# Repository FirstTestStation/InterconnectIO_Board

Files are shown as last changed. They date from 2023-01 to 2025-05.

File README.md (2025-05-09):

# FIRST STATION TEST Interconnect IO Board 600-1000-011

## Project Overview
This project involves the assembly of a custom **Interconnect IO Circuit Board (PCB)** designed to be part of the **First TestStation** project ([FTS](https://FirstTestSTation.github.io/FTS_Website/)). The primary goal of the Interconnect IO board is to provide an interface between instruments and the Unit Under Test (U.U.T).

Many resources, such as **bank relays**, **power relays**, **Digital IO** and **communication interfaces**, have been integrated into the Interconnect IO board. These resources reduce the need for external instruments and maximize the versatility of the interface, allowing for efficient testing and broader functionality.

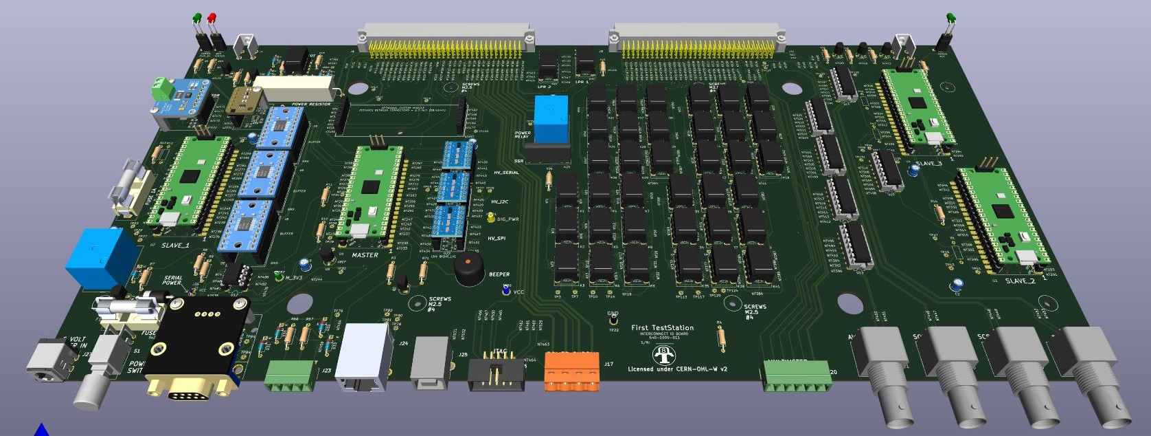
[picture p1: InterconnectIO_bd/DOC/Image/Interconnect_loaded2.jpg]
Board
 

### Design Tools
- [KiCad 7](https://www.kicad.org/download/) - Free software application used to design the PCB.
- [LibreOffice](https://www.libreoffice.org/download/download-libreoffice/) - Free Software application used to create assembly instructions and the Bill of Materials (BOM).
- [PicPick](https://picpick.app/en/) - Free application to capture and document image.

---
### Features
- **Easy Hand Assembly**: Designed with only through-hole components, making it easy to assemble by hand.
- **Socketed Active Components**: To facilitate easy replacement without unsoldering, most active components are mounted on sockets.
- **Cost-Effective Controller**: The low-cost and powerful **Raspberry Pi Pico Microcontroller** is used to interface with the user and control internal electronics.

## Assembly Instructions
   Follow the document [Assembly_Instructions](InterconnectIO_bd/pdf/InterconnectIO_Assembly_Instruction_680-1000.pdf) to complete the assembly of the board.

## Design Files
- [Gerber Files](InterconnectIO_bd/gerber_to_order/) – Gerber files for PCB fabrication, send zip file to manufacturer (JLCPCB is the one used by the project).
- [Assembly Schematic](InterconnectIO_bd/pdf/InterconnectIO_Assembly_diagram_670-1000.pdf) – Parts and value to help hand assemblies of components.
- [Electrical Schematic](InterconnectIO_bd/pdf/interconnectIO_schematic_640-1000.pdf) – Review the full electrical schematic diagram for reference.
- [Bill of Materials (BOM)](InterconnectIO_bd/pdf/BOM_InterconnectIO_Board_610-1000.pdf) – List of components required for assembly.

---

## License

This project is licensed under the terms of the [CERN Open Hardware License Version 2 - Weakly Reciprocal (CERN-OHL-W 2.0)](https://ohwr.org/cern_ohl_w_v2.txt).

See the [LICENSE](./LICENSE) file in this repository for more details.

---

## History
- **Version 1.0**: The initial version of the PCB (600-1010-010) has been assembled and tested. Wiring errors on the UART were identified and corrected manually using wires.
- **Version 1.1**: This version addresses all errors identified in Version 1.0. As of now, Version 1.1 has not yet been assembled or tested.
---

## Contact
For any issues or further questions, feel free to contact me at [daniellockhead@gmail.com] or open an issue on GitHub.

---

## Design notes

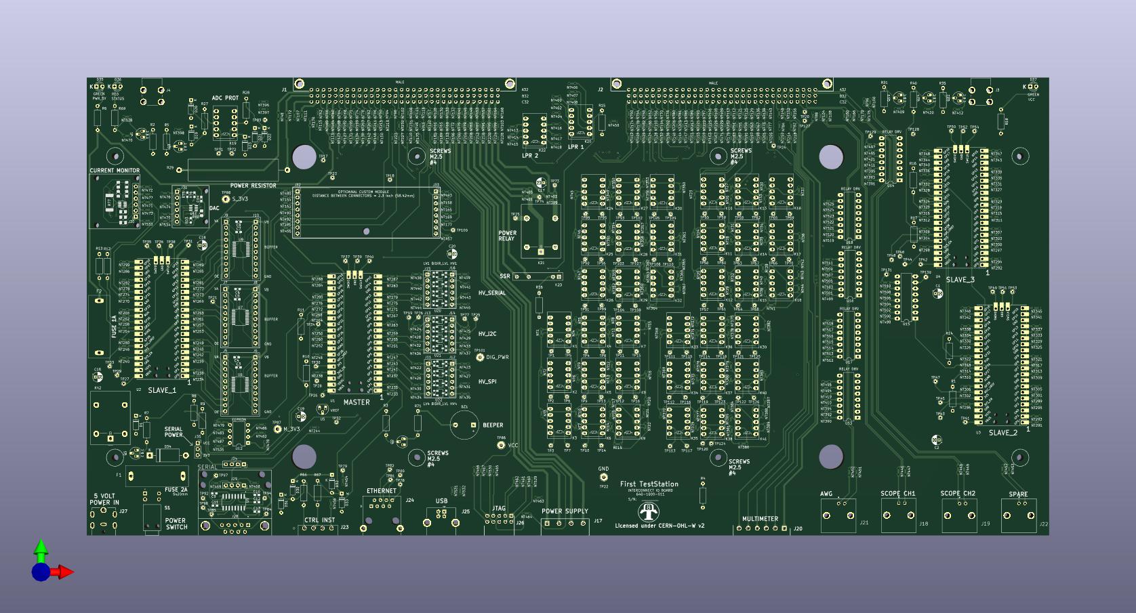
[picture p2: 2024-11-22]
InterconnectIO_bd/DOC/Image/Interconnect_PCB.jpg

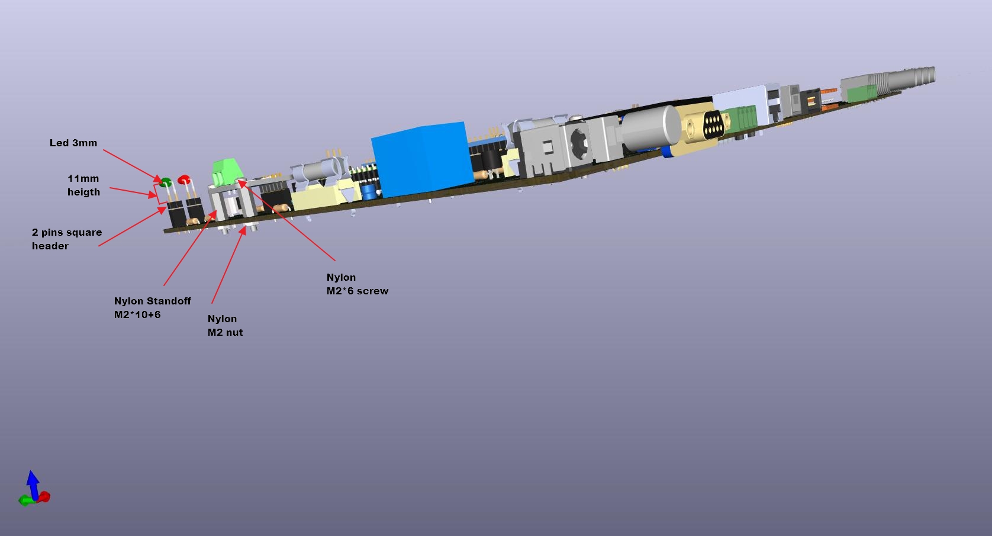
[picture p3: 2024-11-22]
InterconnectIO_bd/DOC/Image/Interconnect_mount3.jpg

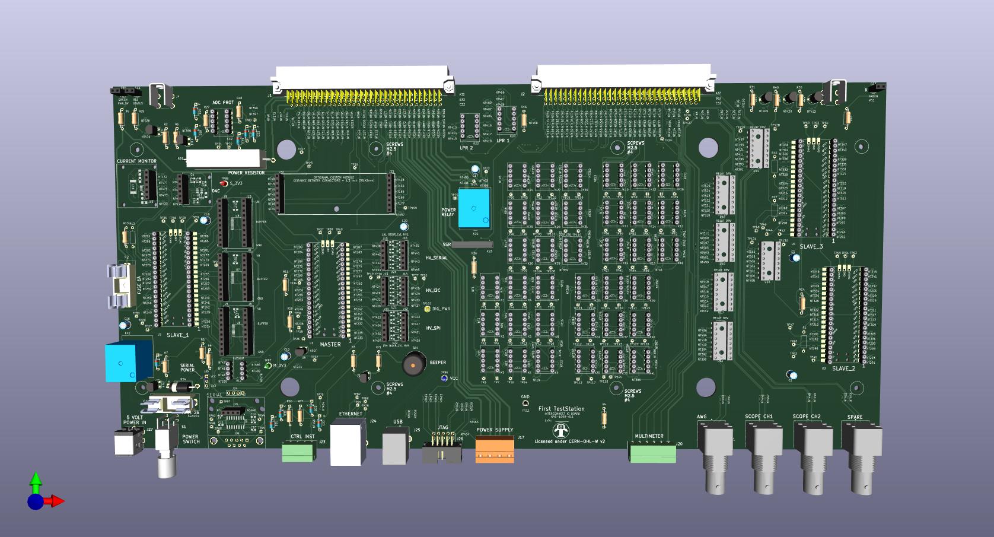
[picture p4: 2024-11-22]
InterconnectIO_bd/DOC/Image/Interconnect_mount.jpg

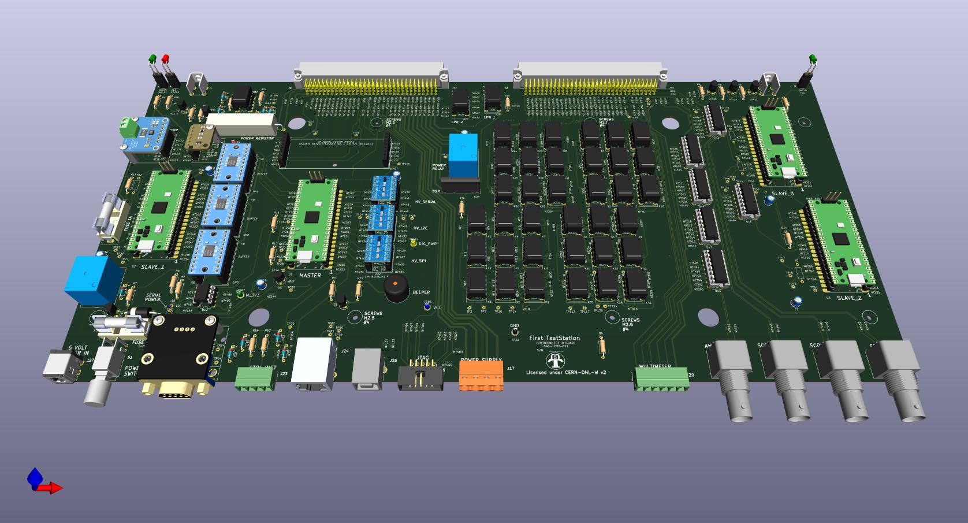
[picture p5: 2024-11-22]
InterconnectIO_bd/DOC/Image/Interconnect_mount2.jpg

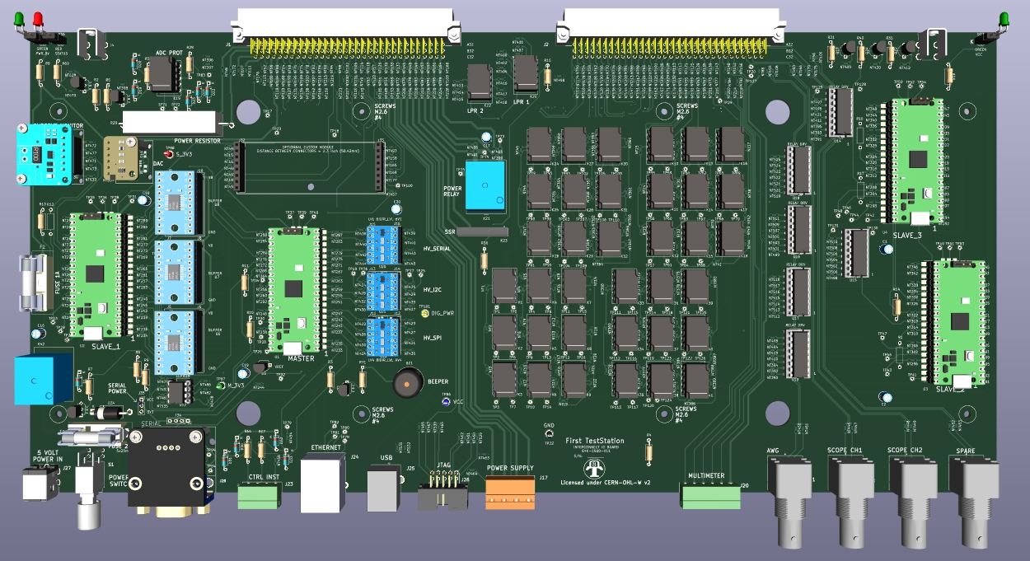
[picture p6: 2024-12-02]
InterconnectIO_bd/DOC/Image/Interconnect_loaded.jpg

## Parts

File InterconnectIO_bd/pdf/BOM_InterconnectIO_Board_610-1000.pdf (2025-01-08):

# BOM InterconnectIO Board

610-1000-011

Component for this board has been selected to be not expensive and available over the world. The quanty specified on the BOM are the required quanty and not the quanty received because most of the components sales by AlieExpress are coming in a lot of 5 or m

ITEM Ref | Qty Value | Component number | Component Link | Footprint
1 | BZ1, | 1 | TMB12A05 | 5V acve Buzzer | hps://www.aliexpress.com/item/4000118703011.html?spm=a2g0o.order_list.order_list_main.124.18751802TGrCM3 | Buzzer_Beeper:Buzzer_12x9.5RM7.6
2 | C1, C2, C16, C17, C18, C19, C20, | 7 | 10uF, 50V | 4 mmx7mm | hps://www.aliexpress.com/item/1005001831366715.html?spm=a2g0o.order_list.order_list_main.128.18751802TGrCM3 | Capacitor_THT:CP_Radial_D4.0mm_P1.50mm
3 | D1, D19, D20, D21, D22, D23, D30, D31, D32, D310 | | 1N4148 | DO-35 | hps://www.aliexpress.com/item/1005002761024460.html?spm=a2g0o.order_list.order_list_main.134.18751802TGrCM3 | Diode_THT:D_DO-35_SOD27_P7.62mm_Horizontal
4 | D34, | 1 | 1N5339B | Zener 5.6V 5W | hps://www.aliexpress.com/item/1005007252102432.html?spm=a2g0o.cart.0.0.382738davUv7k5&mp=1 | Diode_THT:D_DO-201_P15.24mm_Horizontal
5 | D35, D37 | 2 | Green Led | 5 color mixing | hps://www.aliexpress.com/item/32890682652.html?spm=a2g0o.cart.0.0.484b38da3R3jzV&mp=1 | LED_THT:LED_D3.0mm
6 | D36, | 1 | Red Led | 5 color mixing | hps://www.aliexpress.com/item/32890682652.html?spm=a2g0o.cart.0.0.484b38da3R3jzV&mp=1 | LED_THT:LED_D3.0mm_Clear
7 | F1 | 1 | 2A Fuse | 5x20MM 2A | hps://www.aliexpress.com/item/1005004651911205.html?spm=a2g0o.cart.0.0.1c8438daX57J70&mp=1
8 | F2 | 1 | 1A Fuse | 5x20MM 1A | hps://www.aliexpress.com/item/1005004651911205.html?spm=a2g0o.cart.0.0.1c8438daX57J70&mp=1
9 | F1_socket F2_socket, | 2 | MC000827 | MC000827 | hps://www.aliexpress.com/item/1005003663678449.html?spm=a2g0o.order_list.order_list_main.109.5ad91802qJ50cl | SnapEDA Library:MC000827
10 | J1, J2, | 2 | 9001-11961C00A | 396-RA-M | hps://www.aliexpress.com/item/32808173331.html?spm=a2g0o.order_detail.order_detail_item.3.8a9af19cRF49dn | 9001-11961:900111961C00A
11 | J3, J4, | 2 | 7760 | M3 Term Screw | hps://www.digikey.ca/en/products/detail/keystone-electronics/7760/2745938 | SnapEDA Library:7760
12 | J5, J6, J7, J8, J9, J10, | 6 | 10x2.54mm | Cut to length | hps://www.aliexpress.com/item/1000007373786.html?spm=a2g0o.order_list.order_list_main.82.21ef18021ieJzP | Connector_PinSocket_2.54mm:PinSocket_1x10_P2.54mm_Vercal
13 | J11, J12, J13, J14, J15, J16, J30, J31, | 8 | 6x2.54mm | Cut to length | hps://www.aliexpress.com/item/1000007373786.html?spm=a2g0o.order_list.order_list_main.82.21ef18021ieJzP | Connector_PinSocket_2.54mm:PinSocket_1x06_P2.54mm_Vercal
14 | J17, | 1 | 4 Pins 5.08mm | 4P | hps://www.aliexpress.com/item/1005001666625465.html?spm=a2g0o.order_list.order_list_main.134.21ef18021ieJzP | 4pin_5:1146770000
15 | J18, J19,J21,J22 | 4 | BNC | Conn_Coaxial gold plated | hps://www.aliexpress.com/item/1005006866967010.html?spm=a2g0o.cart.0.0.5dcc38daPY7vC2&mp=1 | BNC:TE_1-1337542-0
16 | J20, | 1 | 6 pins 3.81mm | 6P 3.81mm Plug and Socket-A | hps://www.aliexpress.com/item/32880910367.html?spm=a2g0o.order_detail.order_detail_item.3.2a65f19ceWcMGt | 6pin_3:SHDRRA6W80P0X381_1X6_2405X920X700P
17 | J23, | 1 | 4 pins 3.81mm | 4P 3.81mm Plug and Socket-A | hps://www.aliexpress.com/item/32880910367.html?spm=a2g0o.order_detail.order_detail_item.3.7110f19cKK7wMr | 4pins_3:691322310004
18 | J24, | 1 | RJ45 | 8P8C Right Angle No led | hps://www.aliexpress.com/item/32694863099.html?spm=a2g0o.cart.0.0.7fd538dawwnp2x&mp=1 | Connector_RJ:RJ45_Ninigi_GE
19 | J25, | 1 | USB-B1HSB6 | USB_B Right Angle | hps://www.aliexpress.com/item/32834923469.html?spm=a2g0o.order_list.order_list_main.34.21ef18021ieJzP | Connector_USB:USB_B_OST_USB-B1HSxx_Horizontal
20 | J26, | 1 | 2x5 2.54mm RA | 10P | hps://www.aliexpress.com/item/1714360661.html?spm=a2g0o.order_list.order_list_main.29.21ef18021ieJzP | Connector_jtag:SHDRRA10W64P254_2X5_1270X910X880P
21 | J27, | 1 | DC007B | Power Jack 5.5mm | hps://www.aliexpress.com/item/1005003742132830.html?spm=a2g0o.order_detail.order_detail_item.3.5979f19cN90o6a | SnapEDA Library:CUI_PJ-082BH
22 | J29, J34, | 2 | Conn_01x04_Female | Cut to length | hps://www.aliexpress.com/item/1000007373786.html?spm=a2g0o.order_list.order_list_main.82.21ef18021ieJzP | Connector_PinSocket_2.54mm:PinSocket_1x04_P2.54mm_Vercal
23 | J32, J33, | 2 | 8 x 2.54mm Female | Cut to length | hps://www.aliexpress.com/item/1000007373786.html?spm=a2g0o.order_list.order_list_main.82.21ef18021ieJzP | Connector_PinSocket_2.54mm:PinSocket_1x08_P2.54mm_Vercal
24 | J35, | 1 | Wire Bridge | 0 ohm resistor | hps://www.aliexpress.com/item/4000174550644.html?spm=a2g0o.cart.0.0.69c038dacU7SYy&mp=1 | Connector_PinSocket_2.54mm:PinSocket_1x03_P2.54mm_Vercal
25 | K12, K13, K14, K15, K16, K17, K18, K19, K20, K22, K24, K25, K26, K27, K28, K29, K30, K31, K32, K33, K34, K35, K36, K37, K38, K39, K40, K41, | 39 | TQ2-5 | TQ2-5 | hps://www.aliexpress.com/item/1005004349797638.html?spm=a2g0o.order_detail.order_detail_item.3.29bdf19cH6EBpl | Relay_THT:Relay_DPDT_FRT5
26 | Relay Socket | 10 | 1x40P Female Gold | Cut in 5 pins secon | hps://www.aliexpress.com/item/1005005053790061.html?spm=a2g0o.order_list.order_list_main.16.2c1a1802vA8wf5 | oponnal
27 | K21, K42 | 2 | SRD-5VDC-SL-C | SRD-05VDC-SL | hps://www.aliexpress.com/item/1005002916764977.html?spm=a2g0o.cart.0.0.678938dalwTZ3N&mp=1 | Relay_THT:Relay_SPDT_Omron-G5LE-1
28 | K23, | 1 | CPC1706Y | 0-60V 4A | hps://www.digikey.ca/en/products/detail/ixys-integrated-circuits-division/CPC1706Y/3077519?s=N4IgTCBcDaIMIAU4EYDsAGAbATRAXQF8g | SnapEDA Library:RELAY_CPC1706Y
29 | Q1, Q2, Q3, Q5, Q19, Q22, Q24, | 7 | 2N2222 | TO-92 | hps://www.aliexpress.com/item/1005005303849667.html?spm=a2g0o.cart.0.0.5c5438daSYNCOD&mp=1 | Package_TO_SOT_THT:TO-92_Inline
30 | R1, R10, R11, R12, R13, R14, R15,R16, R17, | 9 | 4.7K | 1% 1/4W Resistor Kit | hps://www.aliexpress.com/item/1005001818485416.html?spm=a2g0o.cart.0.0.616b38daL0tFWh&mp=1 | Resistor_THT:R_Axial_DIN0207_L6.3mm_D2.5mm_P10.16mm_Horizontal
31 | R2, R3, R5, R7, R8, R9, R31, R35, R40, | 9 | 10K | 1% 1/4W Resistor Kit | hps://www.aliexpress.com/item/1005001818485416.html?spm=a2g0o.cart.0.0.616b38daL0tFWh&mp=1 | Resistor_THT:R_Axial_DIN0207_L6.3mm_D2.5mm_P10.16mm_Horizontal
32 | R4, R71, | 2 | 0 | 1% 1/4W Low value Resistor Kit | hps://www.aliexpress.com/item/4000174550644.html?spm=a2g0o.cart.0.0.69c038dacU7SYy&mp=1 | Resistor_THT:R_Axial_DIN0207_L6.3mm_D2.5mm_P10.16mm_Horizontal
33 | R6, R27, R28, R66, R67, R18 | 5 | 220 | 1% 1/4W Resistor Kit | hps://www.aliexpress.com/item/1005001818485416.html?spm=a2g0o.cart.0.0.405a38daqyYISw&mp=1 | Resistor_THT:R_Axial_DIN0207_L6.3mm_D2.5mm_P10.16mm_Horizontal
34 | R29, | 1 | 10 | 10W 10R | hps://www.aliexpress.com/item/1005002584950177.html?spm=a2g0o.order_list.order_list_main.76.68501802kRK9e9 | Resistor_THT:R_Axial_Power_L38.0mm_W9.0mm_P45.72mm
35 | R36, | 1 | 470 | 1% 1/4W Resistor Kit | hps://www.aliexpress.com/item/1005001818485416.html?spm=a2g0o.cart.0.0.616b38daL0tFWh&mp=1 | Resistor_THT:R_Axial_DIN0207_L6.3mm_D2.5mm_P10.16mm_Horizontal
36 | R69, | 1 | 150 | 1% 1/4W Resistor Kit | hps://www.aliexpress.com/item/1005001818485416.html?spm=a2g0o.cart.0.0.616b38daL0tFWh&mp=1 | Resistor_THT:R_Axial_DIN0207_L6.3mm_D2.5mm_P10.16mm_Horizontal
37 | S1, | 1 | PB400EEQR1BLK | PB400EEQR1BLK | hps://www.digikey.ca/en/products/detail/e-switch/PB400EEQR1BLK/8042726 | SnapEDA Library:SW_PB400EEQR1BLK
38 | U1, U2, U3, U4, | 4 | Pico | Raspberry Pico Module | hps://www.digikey.ca/en/products/detail/raspberry-pi/SC0915/13624793 | MCU_RaspberryPi_and_Boards:RPi_Pico_SMD_TH
39 | U1_header,U2_header,U3_header,U4_header | 4 | 1x40P Male L-11.96mm | Cut in 20 pins secon | hps://www.aliexpress.com/item/1005005053790061.html?spm=a2g0o.cart.0.0.215538daKAWJrh&mp=1 | Pico round male pins mount on boom of Pico controller
40 | U1_debug,U2_debug,U3_debug,U4_debug | 1 | 1x40P Female Gold | Cut in 3 pins secon | hps://www.aliexpress.com/item/1005005053790061.html?spm=a2g0o.cart.0.0.215538daKAWJrh&mp=1 | Pico 3-pin round socket mount on top of Pico controller (SWD)
41 | U1_dhead,U2_dhead,U3_dhead,U4_dhead | 1 | 1x40P Male L-11.96mm | Cut in 3 pins secon | hps://www.aliexpress.com/item/1005005053790061.html?spm=a2g0o.cart.0.0.215538daKAWJrh&mp=1 | Pico 3-pin round male pins mount on round socket of Pico controller (SWD)
42 | U1_socket,U2_socket,U3_socket,U4_socket | 4 | 1x40P Female Gold | Cut in 20 pins secon | hps://www.aliexpress.com/item/1005005053790061.html?spm=a2g0o.cart.0.0.215538daKAWJrh&mp=1 | Pico round socket mount on PCB
43 | U5, | 1 | LM4040LP-3 | LM4040LP-3 | hps://www.digikey.ca/en/products/detail/texas-instruments/LM4040D30ILPR/1493976 | Package_TO_SOT_THT:TO-92_Inline
44 | U6, U7, U8, | 3 | TXS0108E module | TXS0108E 5pcs | hps://www.aliexpress.com/item/1005005611794764.html?spm=a2g0o.cart.0.0.48ca38daLJipET&mp=1
45 | U9, | 1 | MAX3232 | Serial Module | hps://www.aliexpress.com/item/4000587246651.html?spm=a2g0o.cart.0.0.251f38daKBNFZg&mp=1
46 | U10, | 1 | INA219AxD | Current Monitoring Module | hps://www.aliexpress.com/item/32375566240.html?spm=a2g0o.order_list.order_list_main.44.68501802kRK9e9
47 | U11, | 1 | MCP4725xxx-xCH | DAC Module | hps://www.aliexpress.com/item/1005003301834508.html?spm=a2g0o.order_detail.order_detail_item.9.30154f03ARKf2e
48 | U12, | 1 | 24LC32 | 24LC32 | hps://www.aliexpress.com/item/1005007109141216.html?spm=a2g0o.cart.0.0.110c38dab4kaqM&mp=1 | Package_DIP:DIP-8_W7.62mm
49 | U13, U14, U15, U16, U17, U18, | 6 | ULN2003A | ULN2003AN DIP | hps://www.aliexpress.com/item/1005003321113000.html?spm=a2g0o.order_list.order_list_main.55.68501802kRK9e9 | Package_DIP:DIP-16_W7.62mm_LongPads
50 | U13_socket, U14_socket, U15_socket, U16_socket, U17_socket, U18_socket, | 6 | 16 pin socket | round hole DIP-16p | hps://www.aliexpress.com/item/4000578067926.html?spm=a2g0o.cart.0.0.2bcc38da88bsXx&mp=1 | Package_DIP:DIP-16_W7.62mm_LongPads
51 | U20 U21, U22 | 3 | BSS138 | Logic level converter | hps://www.aliexpress.com/item/1005006096023556.html?spm=a2g0o.cart.0.0.512038daUH9mqE&mp=1
52 | TP22,TP86,TP87,TP88,TP101 | 5 | Testpoint | Black,Blue,Green,Red,Yellow | hps://www.aliexpress.com/item/1005001843784820.html?spm=a2g0o.cart.0.0.7faa38daxJjUNz&mp=1 | TestPoint_Loop_D2.54mm_Drill1.5mm_Beaded
53 | Hardware nylon Standoff | 1 | F-F nylon Standoff | M2 Black nylon mix 300pcs | hps://www.aliexpress.com/item/32869450950.html?spm=a2g0o.cart.0.0.5bee38daupPiNY&mp=1
54 | Hardware metal Screw | 1 | M2.5 | M2.5 600pcs | hps://www.aliexpress.com/item/1005007148394693.html?spm=a2g0o.order_detail.order_detail_item.3.6db7f19c0LlCTk
55 | PCB InterconnectIO Board | 1 | 660-1000-011 | Gerbers to order | hps://jlcpcb.com/
0 | Q26, Q27, Q28, Q29, Q30, Q31, Q32, Q33, Q34, 12 | | BSS138 | BSS138 | Not installed, use already assembled module | Import_library:SOT-23W_SHORT
0 | R42, R43, R44, R45, R46, R47, R48, R49, R50, R5124 | | 10K | R_US | Not installed, use already assembled module | Resistor_SMD:R_0603_1608Metric
0 | R73, R74, R78, R79, R80, R81, R82, | 7 | 10K | R_US | Not installed, use already assembled module | Resistor_SMD:R_0805_2012Metric_Pad1.20x1.40mm_HandSolder
0 | R75, R76, | 2 | 4.7K | R_US | Not installed, use already assembled module | Resistor_SMD:R_0603_1608Metric_Pad0.98x0.95mm_HandSolder
0 | R77, | 1 | 0.1 R_US | | Not installed, use already assembled module | Resistor_SMD:R_2512_6332Metric_Pad1.40x3.35mm_HandSolder
0 | R83, | 1 | 10K | R_US | Not installed, use already assembled module | Resistor_SMD:R_0603_1608Metric_Pad0.98x0.95mm_HandSolder
0 | C3, C4, C5, C6, C7, C8, C13, C14, | 8 | 0.1uF | C_Small | Not installed, use already assembled module | Capacitor_SMD:C_0603_1608Metric_Pad1.08x0.95mm_HandSolder
0 | C9, C10, C11, C12, | 4 | 100n | C_Small | Not installed, use already assembled module | Capacitor_SMD:C_0603_1608Metric_Pad1.08x0.95mm_HandSolder
0 | C15, | 1 | 0.1uF | C_Small | Not installed, use already assembled module | Capacitor_SMD:C_0805_2012Metric_Pad1.18x1.45mm_HandSolder
0 | J28, | 1 | DB9_Female_RA | DB9_Female_MounngHoles | Not installed, use already assembled module | Connector_Dsub:DSUB-9_Female_Horizontal_P2.77x2.84mm_EdgePinOffs et4.94mm_Housed_MounngHolesOffset7.48mm

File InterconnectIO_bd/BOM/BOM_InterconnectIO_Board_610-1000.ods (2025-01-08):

BOM InterconnectIO Board
610-1000-011
Component for this board has been selected to be not expensive and available over the world. The quantity specified on the BOM are the required quantity and not the quantity received because most of the components sales by AlieExpress are coming in a lot of 5 or more.
ITEM | Ref | Qty | Value | Component number | Component Link | Footprint
1 | BZ1, | 1 | TMB12A05 | 5V active Buzzer | https://www.aliexpress.com/item/4000118703011.html | Buzzer_Beeper:Buzzer_12x9.5RM7.6
2 | C1, C2, C16, C17, C18, C19, C20, | 7 | 10uF, 50V | 4 mmx7mm | https://www.aliexpress.com/item/1005001831366715.html | Capacitor_THT:CP_Radial_D4.0mm_P1.50mm
3 | D1, D19, D20, D21, D22, D23, D30, D31, D32, D33, | 10 | 1N4148 | DO-35 | https://www.aliexpress.com/item/1005002761024460.html | Diode_THT:D_DO-35_SOD27_P7.62mm_Horizontal
4 | D34, | 1 | 1N5339B | Zener 5.6V 5W | https://www.aliexpress.com/item/1005007252102432.html?spm=a2g0o.cart.0.0.382738davUv7k5&mp=1 | Diode_THT:D_DO-201_P15.24mm_Horizontal
5 | D35, D37 | 2 | Green Led | 5 color mixing | https://www.aliexpress.com/item/32890682652.html?spm=a2g0o.cart.0.0.484b38da3R3jzV&mp=1 | LED_THT:LED_D3.0mm
6 | D36, | 1 | Red Led | 5 color mixing | https://www.aliexpress.com/item/32890682652.html?spm=a2g0o.cart.0.0.484b38da3R3jzV&mp=1 | LED_THT:LED_D3.0mm_Clear
7 | F1 | 1 | 2A Fuse | 5x20MM 2A | https://www.aliexpress.com/item/1005004651911205.html?spm=a2g0o.cart.0.0.1c8438daX57J70&mp=1
8 | F2 | 1 | 1A Fuse | 5x20MM 1A | https://www.aliexpress.com/item/1005004651911205.html?spm=a2g0o.cart.0.0.1c8438daX57J70&mp=1 (https://www.aliexpress.com/item/1005007252102432.html?spm=a2g0o.cart.0.0.382738davUv7k5&mp=1)
9 | F1_socket F2_socket, | 2 | MC000827 | MC000827 | https://www.aliexpress.com/item/1005003663678449.html | SnapEDA Library:MC000827
10 | J1, J2, | 2 | 9001-11961C00A | 396-RA-M | https://www.aliexpress.com/item/32808173331.html | 9001-11961:900111961C00A
11 | J3, J4, | 2 | 7760 | M3 Term Screw | https://www.digikey.ca/en/products/detail/keystone-electronics/7760/2745938 | SnapEDA Library:7760
12 | J5, J6, J7, J8, J9, J10, | 6 | 10x2.54mm | Cut to length | https://www.aliexpress.com/item/1000007373786.html | Connector_PinSocket_2.54mm:PinSocket_1x10_P2.54mm_Vertical
13 | J11, J12, J13, J14, J15, J16, J30, J31, | 8 | 6x2.54mm | Cut to length | https://www.aliexpress.com/item/1000007373786.html | Connector_PinSocket_2.54mm:PinSocket_1x06_P2.54mm_Vertical
14 | J17, | 1 | 4 Pins 5.08mm | 4P | https://www.aliexpress.com/item/1005001666625465.html | 4pin_5:1146770000
15 | J18, J19,J21,J22 | 4 | BNC | Conn_Coaxial gold plated | https://www.aliexpress.com/item/1005006866967010.html?spm=a2g0o.cart.0.0.5dcc38daPY7vC2&mp=1 | BNC:TE_1-1337542-0
16 | J20, | 1 | 6 pins 3.81mm | 6P 3.81mm Plug and Socket-A | https://www.aliexpress.com/item/32880910367.html | 6pin_3:SHDRRA6W80P0X381_1X6_2405X920X700P
17 | J23, | 1 | 4 pins 3.81mm | 4P 3.81mm Plug and Socket-A | https://www.aliexpress.com/item/32880910367.html | 4pins_3:691322310004
18 | J24, | 1 | RJ45 | 8P8C Right Angle No led | https://www.aliexpress.com/item/32694863099.html?spm=a2g0o.cart.0.0.7fd538dawwnp2x&mp=1 | Connector_RJ:RJ45_Ninigi_GE
19 | J25, | 1 | USB-B1HSB6 | USB_B Right Angle | https://www.aliexpress.com/item/32834923469.html | Connector_USB:USB_B_OST_USB-B1HSxx_Horizontal
20 | J26, | 1 | 2x5 2.54mm RA | 10P | https://www.aliexpress.com/item/1714360661.html | Connector_jtag:SHDRRA10W64P254_2X5_1270X910X880P
21 | J27, | 1 | DC007B | Power Jack 5.5mm | https://www.aliexpress.com/item/1005003742132830.html | SnapEDA Library:CUI_PJ-082BH
22 | J29, J34, | 2 | Conn_01x04_Female | Cut to length | https://www.aliexpress.com/item/1000007373786.html | Connector_PinSocket_2.54mm:PinSocket_1x04_P2.54mm_Vertical
23 | J32, J33, | 2 | 8 x 2.54mm Female | Cut to length | https://www.aliexpress.com/item/1000007373786.html | Connector_PinSocket_2.54mm:PinSocket_1x08_P2.54mm_Vertical
24 | J35, | 1 | Wire Bridge | 0 ohm resistor | https://www.aliexpress.com/item/4000174550644.html?spm=a2g0o.cart.0.0.69c038dacU7SYy&mp=1 | Connector_PinSocket_2.54mm:PinSocket_1x03_P2.54mm_Vertical
25 | K1, K2, K3, K4, K5, K6, K7, K8, K9, K10, K11, K12, K13, K14, K15, K16, K17, K18, K19, K20, K22, K24, K25, K26, K27, K28, K29, K30, K31, K32, K33, K34, K35, K36, K37, K38, K39, K40, K41, | 39 | TQ2-5 | TQ2-5 | https://www.aliexpress.com/item/1005004349797638.html | Relay_THT:Relay_DPDT_FRT5
26 | Relay Socket | 10 | 1x40P Female Gold | Cut in 5 pins section | https://www.aliexpress.com/item/1005005053790061.html | optionnal
27 | K21, K42 | 2 | SRD-5VDC-SL-C | SRD-05VDC-SL | https://www.aliexpress.com/item/1005002916764977.html?spm=a2g0o.cart.0.0.678938dalwTZ3N&mp=1 | Relay_THT:Relay_SPDT_Omron-G5LE-1
28 | K23, | 1 | CPC1706Y | 0-60V 4A | https://www.digikey.ca/en/products/detail/ixys-integrated-circuits-division/CPC1706Y/3077519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 | SnapEDA Library:RELAY_CPC1706Y
29 | Q1, Q2, Q3, Q5, Q19, Q22, Q24, | 7 | 2N2222 | TO-92 | https://www.aliexpress.com/item/1005005303849667.html?spm=a2g0o.cart.0.0.5c5438daSYNCOD&mp=1 | Package_TO_SOT_THT:TO-92_Inline
30 | R1, R10, R11, R12, R13, R14, R15,R16, R17, | 9 | 4.7K | 1% 1/4W Resistor Kit | https://www.aliexpress.com/item/1005001818485416.html?spm=a2g0o.cart.0.0.616b38daL0tFWh&mp=1 | Resistor_THT:R_Axial_DIN0207_L6.3mm_D2.5mm_P10.16mm_Horizontal
31 | R2, R3, R5, R7, R8, R9, R31, R35, R40, | 9 | 10K | 1% 1/4W Resistor Kit | https://www.aliexpress.com/item/1005001818485416.html?spm=a2g0o.cart.0.0.616b38daL0tFWh&mp=1 | Resistor_THT:R_Axial_DIN0207_L6.3mm_D2.5mm_P10.16mm_Horizontal
32 | R4, R71, | 2 | 0 | 1% 1/4W Low value Resistor Kit | https://www.aliexpress.com/item/4000174550644.html?spm=a2g0o.cart.0.0.69c038dacU7SYy&mp=1 | Resistor_THT:R_Axial_DIN0207_L6.3mm_D2.5mm_P10.16mm_Horizontal
33 | R6, R27, R28, R66, R67, R18 | 5 | 220 | 1% 1/4W Resistor Kit | https://www.aliexpress.com/item/1005001818485416.html?spm=a2g0o.cart.0.0.405a38daqyYISw&mp=1 | Resistor_THT:R_Axial_DIN0207_L6.3mm_D2.5mm_P10.16mm_Horizontal
34 | R29, | 1 | 10 | 10W 10R | https://www.aliexpress.com/item/1005002584950177.html | Resistor_THT:R_Axial_Power_L38.0mm_W9.0mm_P45.72mm
35 | R36, | 1 | 470 | 1% 1/4W Resistor Kit | https://www.aliexpress.com/item/1005001818485416.html?spm=a2g0o.cart.0.0.616b38daL0tFWh&mp=1 | Resistor_THT:R_Axial_DIN0207_L6.3mm_D2.5mm_P10.16mm_Horizontal
36 | R69, | 1 | 150 | 1% 1/4W Resistor Kit | https://www.aliexpress.com/item/1005001818485416.html?spm=a2g0o.cart.0.0.616b38daL0tFWh&mp=1 | Resistor_THT:R_Axial_DIN0207_L6.3mm_D2.5mm_P10.16mm_Horizontal
37 | S1, | 1 | PB400EEQR1BLK | PB400EEQR1BLK | https://www.digikey.ca/en/products/detail/e-switch/PB400EEQR1BLK/8042726 | SnapEDA Library:SW_PB400EEQR1BLK
38 | U1, U2, U3, U4, | 4 | Pico | Raspberry Pico Module | https://www.digikey.ca/en/products/detail/raspberry-pi/SC0915/13624793 | MCU_RaspberryPi_and_Boards:RPi_Pico_SMD_TH
39 | U1_header,U2_header,U3_header,U4_header | 4 | 1x40P Male L-11.96mm | Cut in 20 pins section | https://www.aliexpress.com/item/1005005053790061.html?spm=a2g0o.cart.0.0.215538daKAWJrh&mp=1 | Pico round male pins mount on bottom of Pico controller
40 | U1_debug,U2_debug,U3_debug,U4_debug | 1 | 1x40P Female Gold | Cut in 3 pins section | https://www.aliexpress.com/item/1005005053790061.html?spm=a2g0o.cart.0.0.215538daKAWJrh&mp=1 | Pico 3-pin round socket mount on top of Pico controller (SWD)
41 | U1_dhead,U2_dhead,U3_dhead,U4_dhead | 1 | 1x40P Male L-11.96mm | Cut in 3 pins section | https://www.aliexpress.com/item/1005005053790061.html?spm=a2g0o.cart.0.0.215538daKAWJrh&mp=1 | Pico 3-pin round male pins mount on round socket of Pico controller (SWD)
42 | U1_socket,U2_socket,U3_socket,U4_socket | 4 | 1x40P Female Gold | Cut in 20 pins section | https://www.aliexpress.com/item/1005005053790061.html?spm=a2g0o.cart.0.0.215538daKAWJrh&mp=1 | Pico round socket mount on PCB
43 | U5, | 1 | LM4040LP-3 | LM4040LP-3 | https://www.digikey.ca/en/products/detail/texas-instruments/LM4040D30ILPR/1493976 | Package_TO_SOT_THT:TO-92_Inline
44 | U6, U7, U8, | 3 | TXS0108E module | TXS0108E 5pcs | https://www.aliexpress.com/item/1005005611794764.html?spm=a2g0o.cart.0.0.48ca38daLJipET&mp=1
45 | U9, | 1 | MAX3232 | Serial Module | https://www.aliexpress.com/item/4000587246651.html?spm=a2g0o.cart.0.0.251f38daKBNFZg&mp=1
46 | U10, | 1 | INA219AxD | Current Monitoring Module | https://www.aliexpress.com/item/32375566240.html
47 | U11, | 1 | MCP4725xxx-xCH | DAC Module | https://www.aliexpress.com/item/1005003301834508.html
48 | U12, | 1 | 24LC32 | 24LC32 | https://www.aliexpress.com/item/1005007109141216.html?spm=a2g0o.cart.0.0.110c38dab4kaqM&mp=1 | Package_DIP:DIP-8_W7.62mm
49 | U13, U14, U15, U16, U17, U18, | 6 | ULN2003A | ULN2003AN DIP | https://www.aliexpress.com/item/1005003321113000.html | Package_DIP:DIP-16_W7.62mm_LongPads
50 | U13_socket, U14_socket, U15_socket, U16_socket, U17_socket, U18_socket, | 6 | 16 pin socket | round hole DIP-16p | https://www.aliexpress.com/item/4000578067926.html?spm=a2g0o.cart.0.0.2bcc38da88bsXx&mp=1 | Package_DIP:DIP-16_W7.62mm_LongPads
51 | U20 U21, U22 | 3 | BSS138 | Logic level converter | https://www.aliexpress.com/item/1005006096023556.html?spm=a2g0o.cart.0.0.512038daUH9mqE&mp=1
52 | TP22,TP86,TP87,TP88,TP101 | 5 | Testpoint | Black,Blue,Green,Red,Yellow | https://www.aliexpress.com/item/1005001843784820.html?spm=a2g0o.cart.0.0.7faa38daxJjUNz&mp=1 | TestPoint_Loop_D2.54mm_Drill1.5mm_Beaded
53 | Hardware nylon Standoff | 1 | F-F nylon Standoff | M2 Black nylon mix 300pcs | https://www.aliexpress.com/item/32869450950.html?spm=a2g0o.cart.0.0.5bee38daupPiNY&mp=1
54 | Hardware metal Screw | 1 | M2.5 | M2.5 600pcs | https://www.aliexpress.com/item/1005007148394693.html
55 | PCB InterconnectIO Board | 1 | 660-1000-011 | Gerbers to order | https://jlcpcb.com/
0 | Q26, Q27, Q28, Q29, Q30, Q31, Q32, Q33, Q34, Q35, Q36, Q37, | 12 | BSS138 | BSS138 | Not installed, use already assembled module | Import_library:SOT-23W_SHORT
0 | R42, R43, R44, R45, R46, R47, R48, R49, R50, R51, R52, R53, R54, R55, R56, R57, R58, R59, R60, R61, R62, R63, R64, R65, | 24 | 10K | R_US | Not installed, use already assembled module | Resistor_SMD:R_0603_1608Metric
0 | R73, R74, R78, R79, R80, R81, R82, | 7 | 10K | R_US | Not installed, use already assembled module | Resistor_SMD:R_0805_2012Metric_Pad1.20x1.40mm_HandSolder
0 | R75, R76, | 2 | 4.7K | R_US | Not installed, use already assembled module | Resistor_SMD:R_0603_1608Metric_Pad0.98x0.95mm_HandSolder
0 | R77, | 1 | 0.1 | R_US | Not installed, use already assembled module | Resistor_SMD:R_2512_6332Metric_Pad1.40x3.35mm_HandSolder
0 | R83, | 1 | 10K | R_US | Not installed, use already assembled module | Resistor_SMD:R_0603_1608Metric_Pad0.98x0.95mm_HandSolder
0 | C3, C4, C5, C6, C7, C8, C13, C14, | 8 | 0.1uF | C_Small | Not installed, use already assembled module | Capacitor_SMD:C_0603_1608Metric_Pad1.08x0.95mm_HandSolder
0 | C9, C10, C11, C12, | 4 | 100n | C_Small | Not installed, use already assembled module | Capacitor_SMD:C_0603_1608Metric_Pad1.08x0.95mm_HandSolder
0 | C15, | 1 | 0.1uF | C_Small | Not installed, use already assembled module | Capacitor_SMD:C_0805_2012Metric_Pad1.18x1.45mm_HandSolder
0 | J28, | 1 | DB9_Female_RA | DB9_Female_MountingHoles | Not installed, use already assembled module | Connector_Dsub:DSUB-9_Female_Horizontal_P2.77x2.84mm_EdgePinOffset4.94mm_Housed_MountingHolesOffset7.48mm

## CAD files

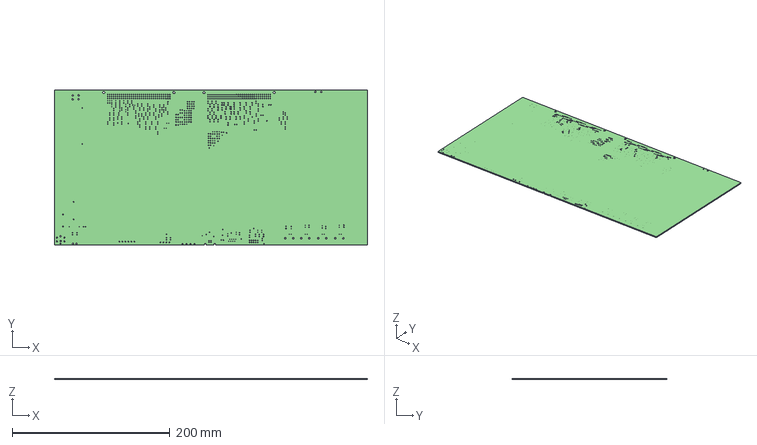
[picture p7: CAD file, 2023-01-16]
Interconnect.step
396.5 x 196.6 x 1.60 mm

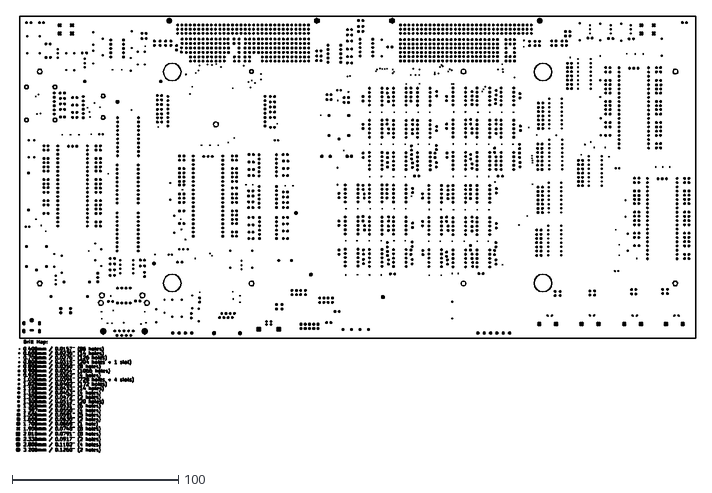
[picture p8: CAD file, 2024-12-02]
InterconnectIO_bd/Interconnect-gerbers/Interconnect-PTH-drl_map.dxf
408.5 x 262.4

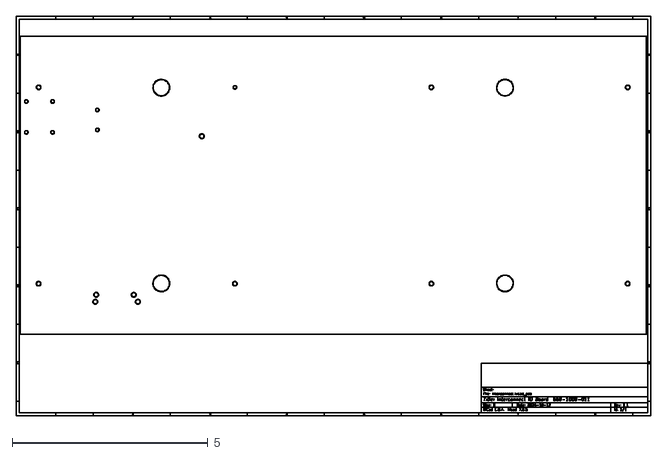
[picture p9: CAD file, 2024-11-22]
InterconnectIO_bd/Interconnect-gerbers/Interconnect-Edge_Cuts.dxf
16.2 x 10.2

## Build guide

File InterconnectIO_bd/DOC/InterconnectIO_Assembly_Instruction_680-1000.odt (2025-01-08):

INTERCONNECT IO BOARD ASSEMBLY INSTRUCTION

680-1000-010

This document provides detailed instructions on how to build the Interconnect IO board.

The board has been designed to be assembled by hand or by automatic machine if larger quantities are required. In this document, the instructions are for the hand assembly method.

In the hand assembly method, component sockets will be used for most parts to facilitate component replacement and make repairs easier. Even though the board includes locations for surface mount components, these will not be used. Instead, pre-built modules will be mounted on sockets to simplify the assembly process.

Two types of socket headers will be used:

1. Square header type:

This socket is used when square pins are involved. The pre-built modules use square pins and require a matching socket to ensure a solid mechanical connection.

To minimize the number of different parts to purchase, we selected the longer 40-socket headers, which can be cut to the required length as needed.

2. Round hole header type:

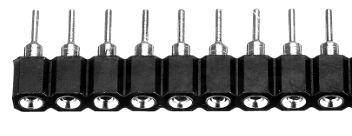
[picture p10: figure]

The round hole header type is preferred due to its smaller size, lower contact resistance and versatility. It can be used directly to mount through-hole electronic components, such as relays and integrated circuits. A round hole male header is required to match with the round hole female header when components do not have pins pre-installed. In the case of the Interconnect IO board, the Raspberry Pi Pico controller will be mounted using a round hole male header.

### Assembly Strategy

To facilitate hand soldering of components, the suggested strategy is to solder all the round circular sockets first. Achieving straight alignment of the round sockets can be tricky and requires some practical experience.

Once the round sockets are soldered, the other components can be installed, following the rule of soldering smaller components first, then moving on to larger ones.

### ASSEMBLY INSTRUCTIONS

Follow these steps to successfully assemble the PCB:

#### Preparation

- Ensure you have the required components and tools (e.g., soldering iron, flux, multimeter).
- Review the Bill of Materials (BOM) to ensure all parts are available.
- Refer to the document Interconnect_IO_Assembly_diagram.pdf to identify the component values to be installed.
- Do not mount components marked N.A. (Not Assembled).
- Do not mount surface-mount technology (SMT) components, as pre-assembled modules will be used in their place.

The picture below of the Interconnect IO Board shows all parts to be soldered.

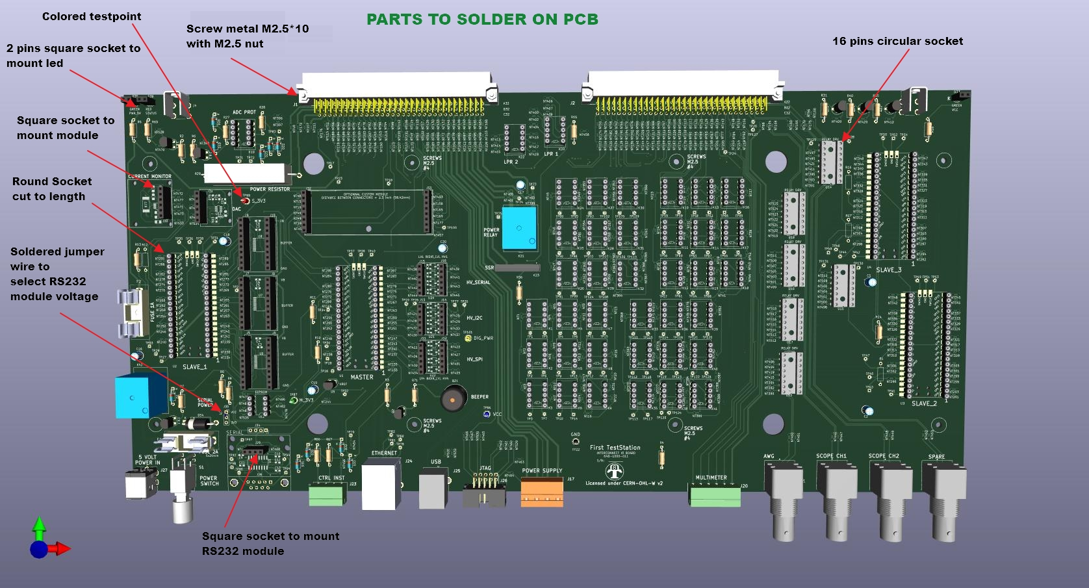
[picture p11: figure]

### Step-by-Step Soldering Instructions

1. Solder Round Pin Sockets: Begin by soldering the round pin sockets (cut to length) for components such as the Microcontroller, ICs, and relays.
2. Solder 16-Pin Sockets: Solder the 16-pin sockets to mount integrated circuits. If 16-pin round sockets are unavailable, round socket headers can be used as an alternative.
3. Solder Square Pin Sockets: Next, solder the square pin sockets (cut to length) at the pre-assembled module locations. Refer to the board picture for correct placement.
4. Solder LED Sockets: The front panel LEDs are mounted on square pins and require 2-pin square socket headers. Solder the 2-pin headers in the LED positions.
5. Install Large Connectors: Place large connectors J1 and J2 on the PCB. Install the retaining screws before soldering to ensure they are securely mounted.
6. Install Smaller Components: Start by soldering the smaller components, such as resistors, capacitors, and test points, before moving on to larger components.
7. Solder Other Connectors: Attach and solder all remaining connectors.
8. Solder Pins Header on Pico: Solder 2 x 20 round pin headers on the bottom of the Pico module. If software code modifications are necessary, solder a 3-pin round socket on the top of the module for debugging. A 3-pin round header will be mounted on top of the 3-pin socket to function as a sacrificial connector.

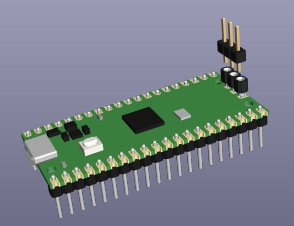
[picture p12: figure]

9. Solder Module Pins Header: Pre-built modules often come with unsoldered header pins. If this is the case, solder the pin headers onto the module before installation. Solder pins header on the bottom of module.
10. Solder LEDs to the 2-Pin Header: Solder each LED to the 2-pin header. Ensure you check the polarity by identifying the flat surface of the LED, which indicates the negative side. Bend the LED at a right angle, as shown in the picture, so that the top of the LED is positioned 11mm from the header base, transforming it into a right-angle LED. Repeat this process for all three LEDs.

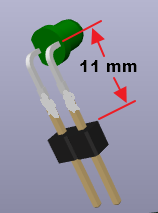
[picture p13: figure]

A this point, the soldering is complete and only parts on socket need to be installed.

### Step-by-Step Mounting Parts Instructions

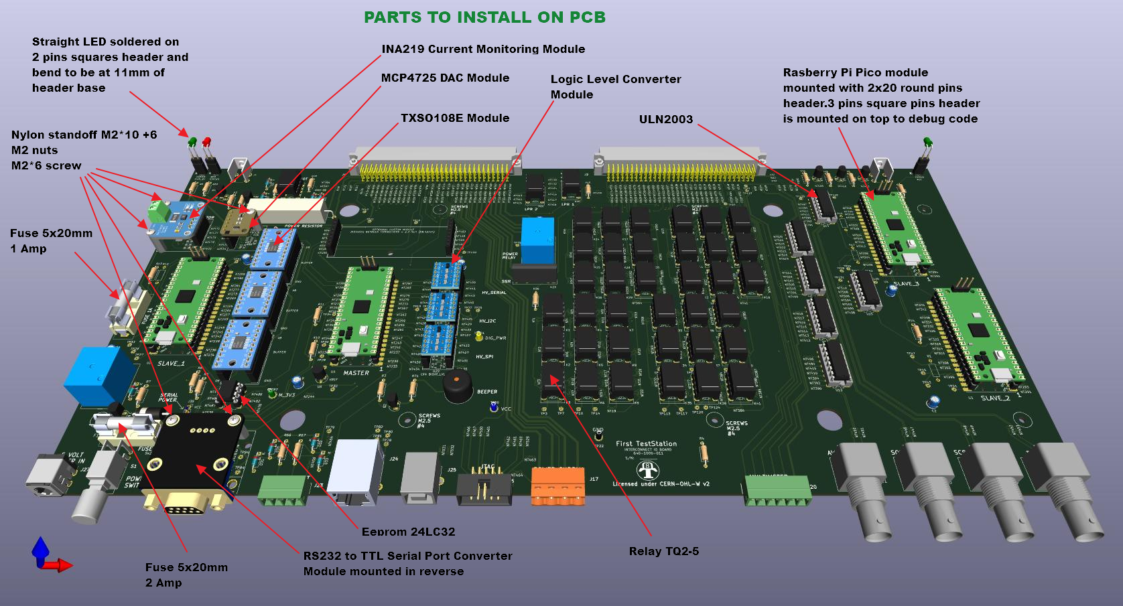
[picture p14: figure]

1. Mount Relays: Start by installing all the relays. Ensure that each relay is installed with the correct polarity (refer to the picture for guidance).
2. Mount Integrated Circuits: Next, install the integrated circuits. Make sure to align pin 1 of each integrated circuit with the pin 1 marking on the board.
3. Mount module with double headers: Next install logic level converter module and buffer module TXS0108E.

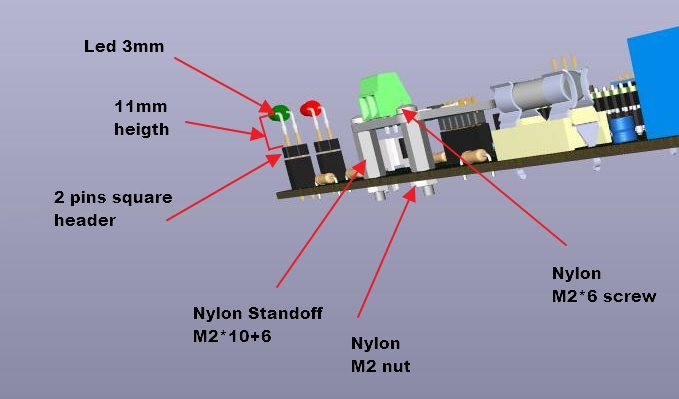
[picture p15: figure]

4. Mount the standoffs: Install the nylon standoff and secure them with a nut on the bottom of the board (refer to the picture to find location of standoff)
5. Mount Single header module: Mount IN219 module and secure them with screws. Repeat procdeure for the DAC module and the RS232 module.
6. Mount Pico Master Module: Program one Raspberry Pi Pico with the Master software. Follow the instructions from InterconnectIO_Master GitHub Repository (https://github.com/dlock8/InterconnectIO_Master). Once programmed, install the Pico on the Board at the location marked "MASTER." Ensure the module is installed in the correct orientation.
7. Mount Pico Slave Modules: Program three Raspberry Pi Pico with the Slave software. Follow the instructions from InterconnectIO_Slave GitHub Repository (https://github.com/dlock8/InterconnectIO_Slave). Once programmed, install the Pico on the Board at the location marked "SLAVE_x." Ensure the module is installed in the correct orientation.
8. Mount Leds module: Finally mount the Led under header to the board following positions and colors.
9. Install Fuse: Install the fuse of the specified value (as marked on the board silkscreen) into the fuse sockets.

At this point, the board assembly is complete, and initial testing can be performed.

### TESTING

1. Shorts Verification: Using a multimeter, verify that there are no shorts present between all the test points: VCC, GND, M_3V3, S_3V3, and DIG_PWR. If any shorts are detected, make the necessary corrections before applying power to the board.
2. First Power On:
  - The green LED D37 is ON (5V indicator).
  - The LED on the Pico module is slowly flashing (indicating Pico heartbeat).
  - The RS232 module is powered on (the onboard red LED is ON).
  - Using a multimeter, verify the 5V value between the VCC and GND test points.
  - Using a multimeter, verify the 3.3V value between the M_3V3 and GND test points.
  - Using a multimeter, verify the 3.3V value between the S_3V3 and GND test points.
3. Test Serial Communication: Connect the computer's serial port to the InterconnectIO Board's serial port using protocol **N81** and set the baud rate to **115200**. Using a terminal program on the computer, send the SCPI command `*IDN?` and verify if the board responds correctly with an identification message.

Initial testing is complete. Comprehensive testing of the board will require additional hardware and will be included in the First Test Station documentation.

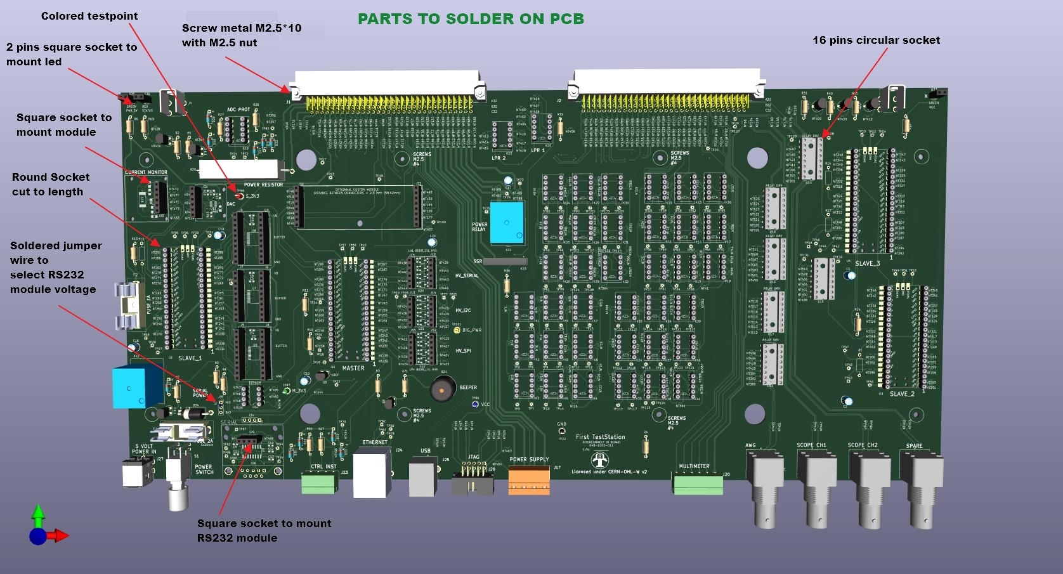
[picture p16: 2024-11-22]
InterconnectIO_bd/DOC/Image/Interconnect_mount_instruction.jpg

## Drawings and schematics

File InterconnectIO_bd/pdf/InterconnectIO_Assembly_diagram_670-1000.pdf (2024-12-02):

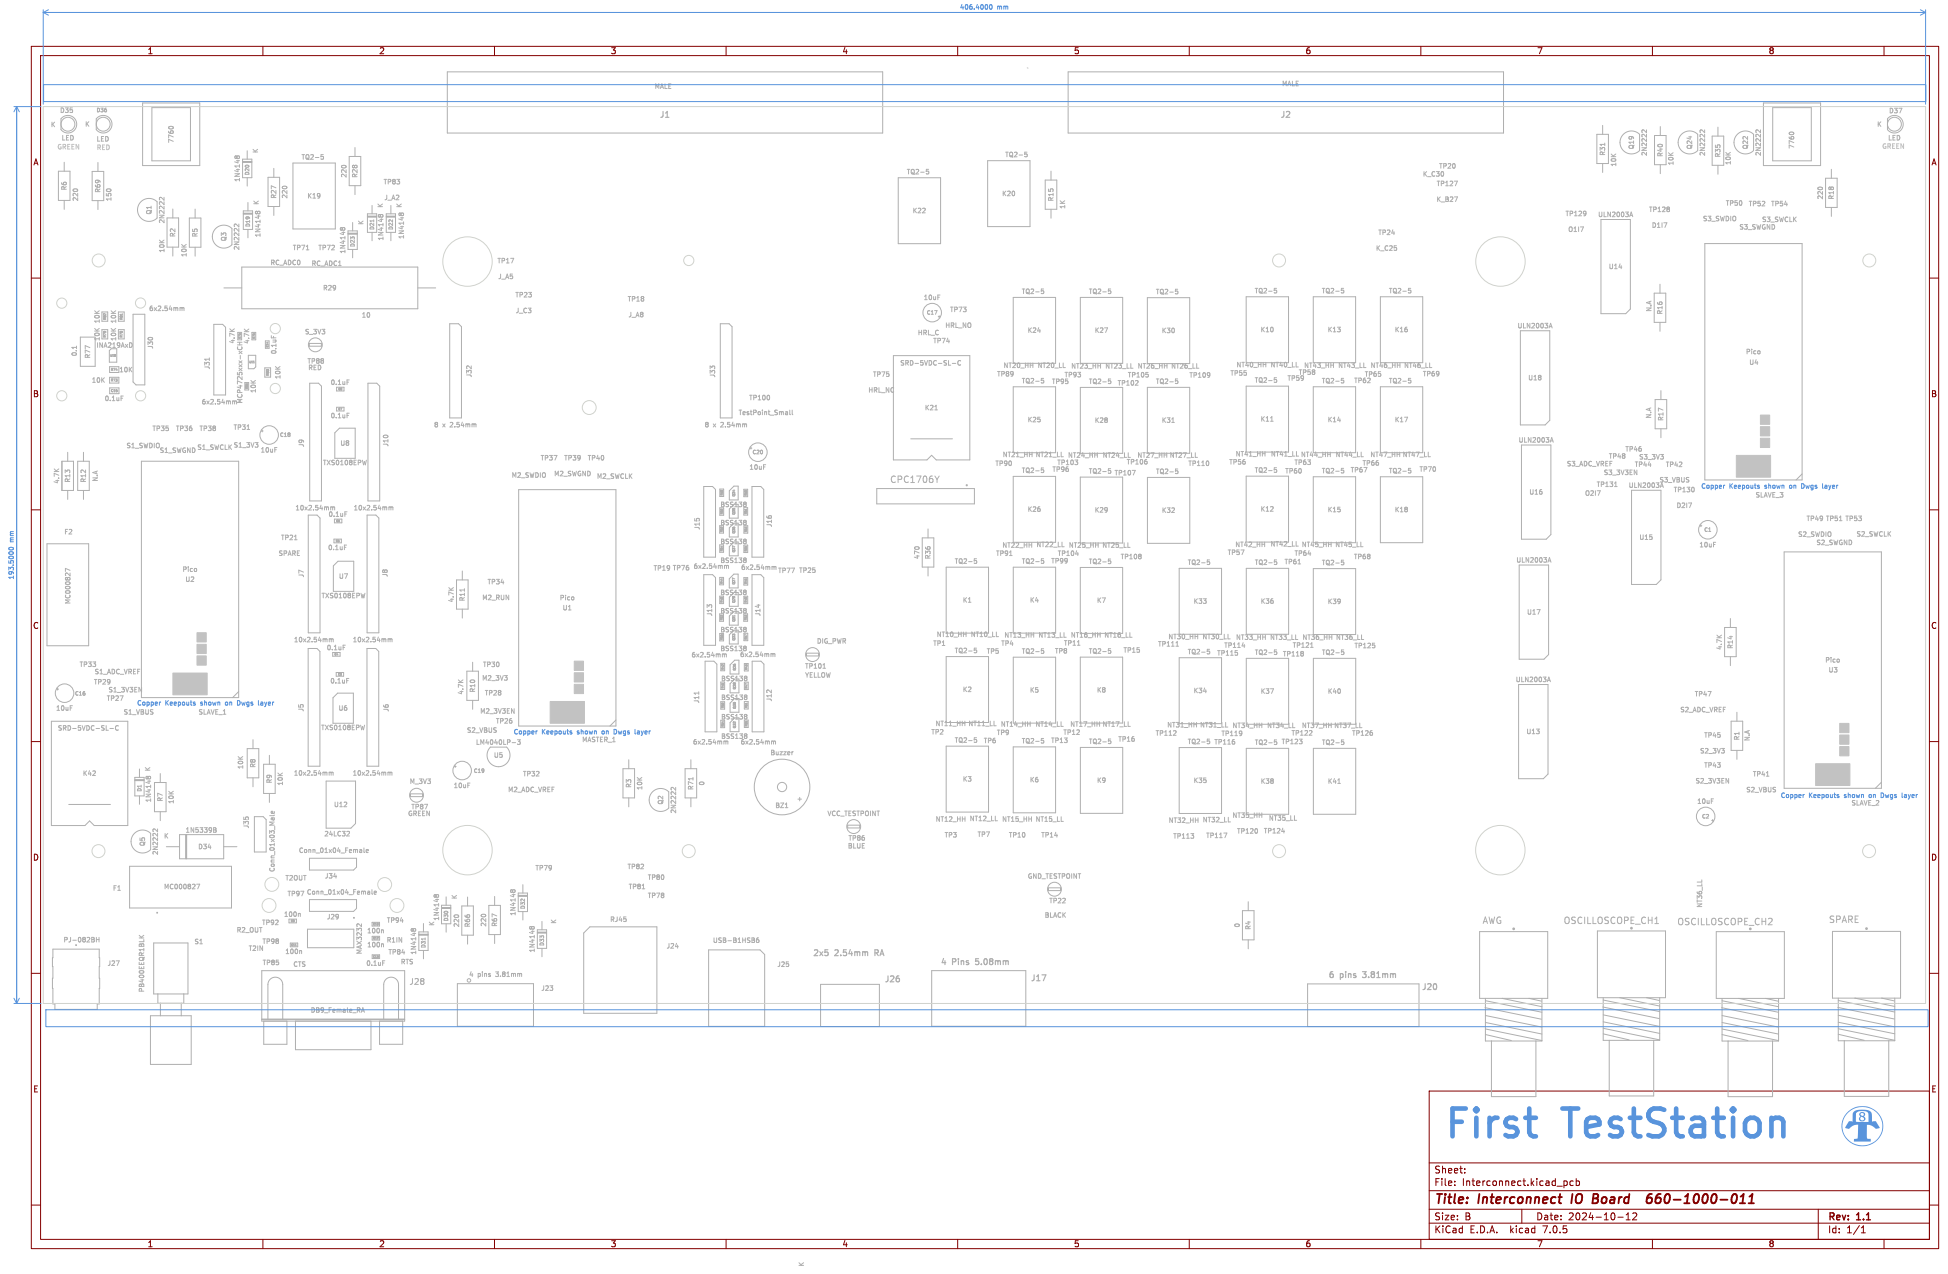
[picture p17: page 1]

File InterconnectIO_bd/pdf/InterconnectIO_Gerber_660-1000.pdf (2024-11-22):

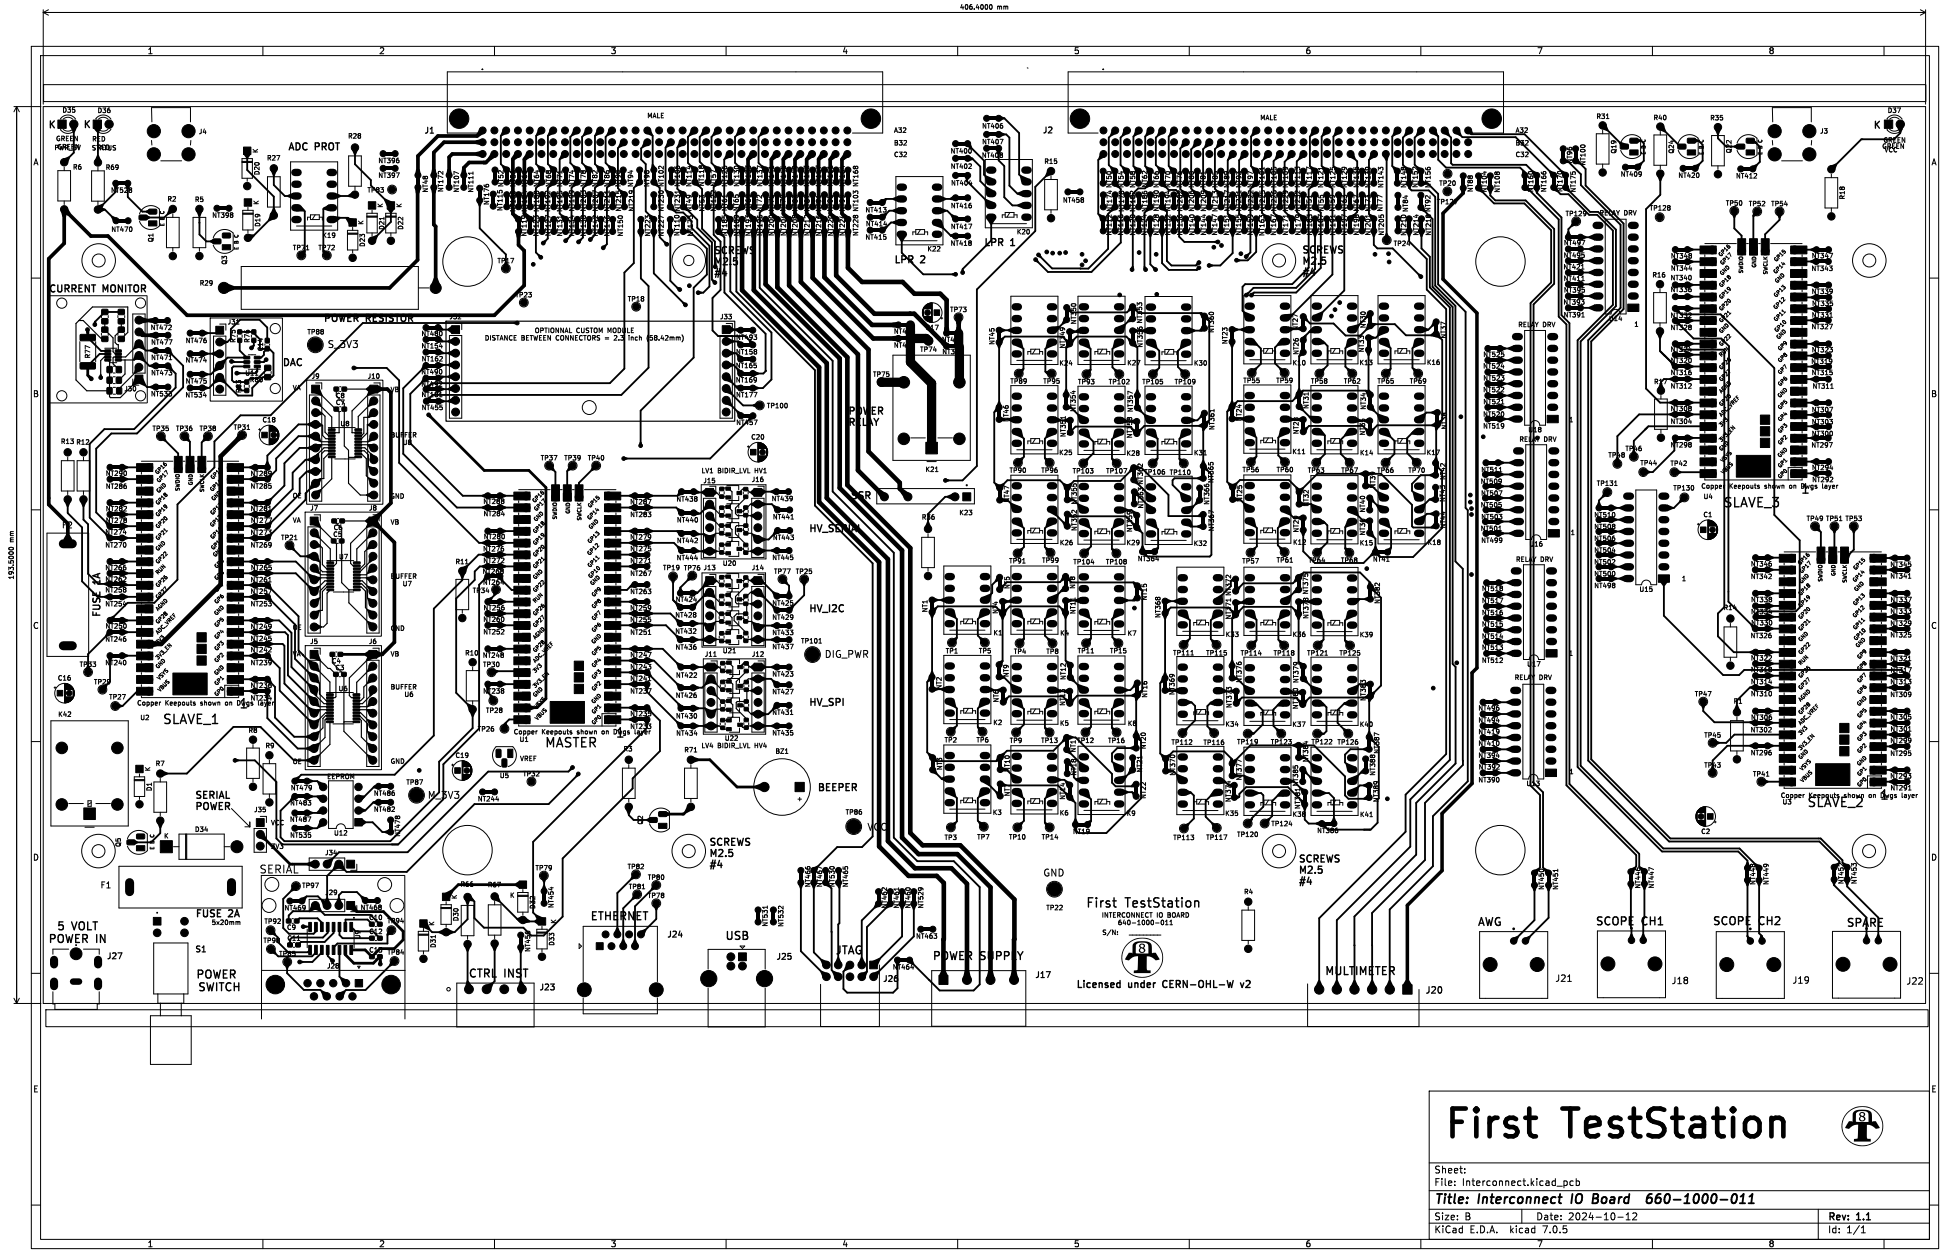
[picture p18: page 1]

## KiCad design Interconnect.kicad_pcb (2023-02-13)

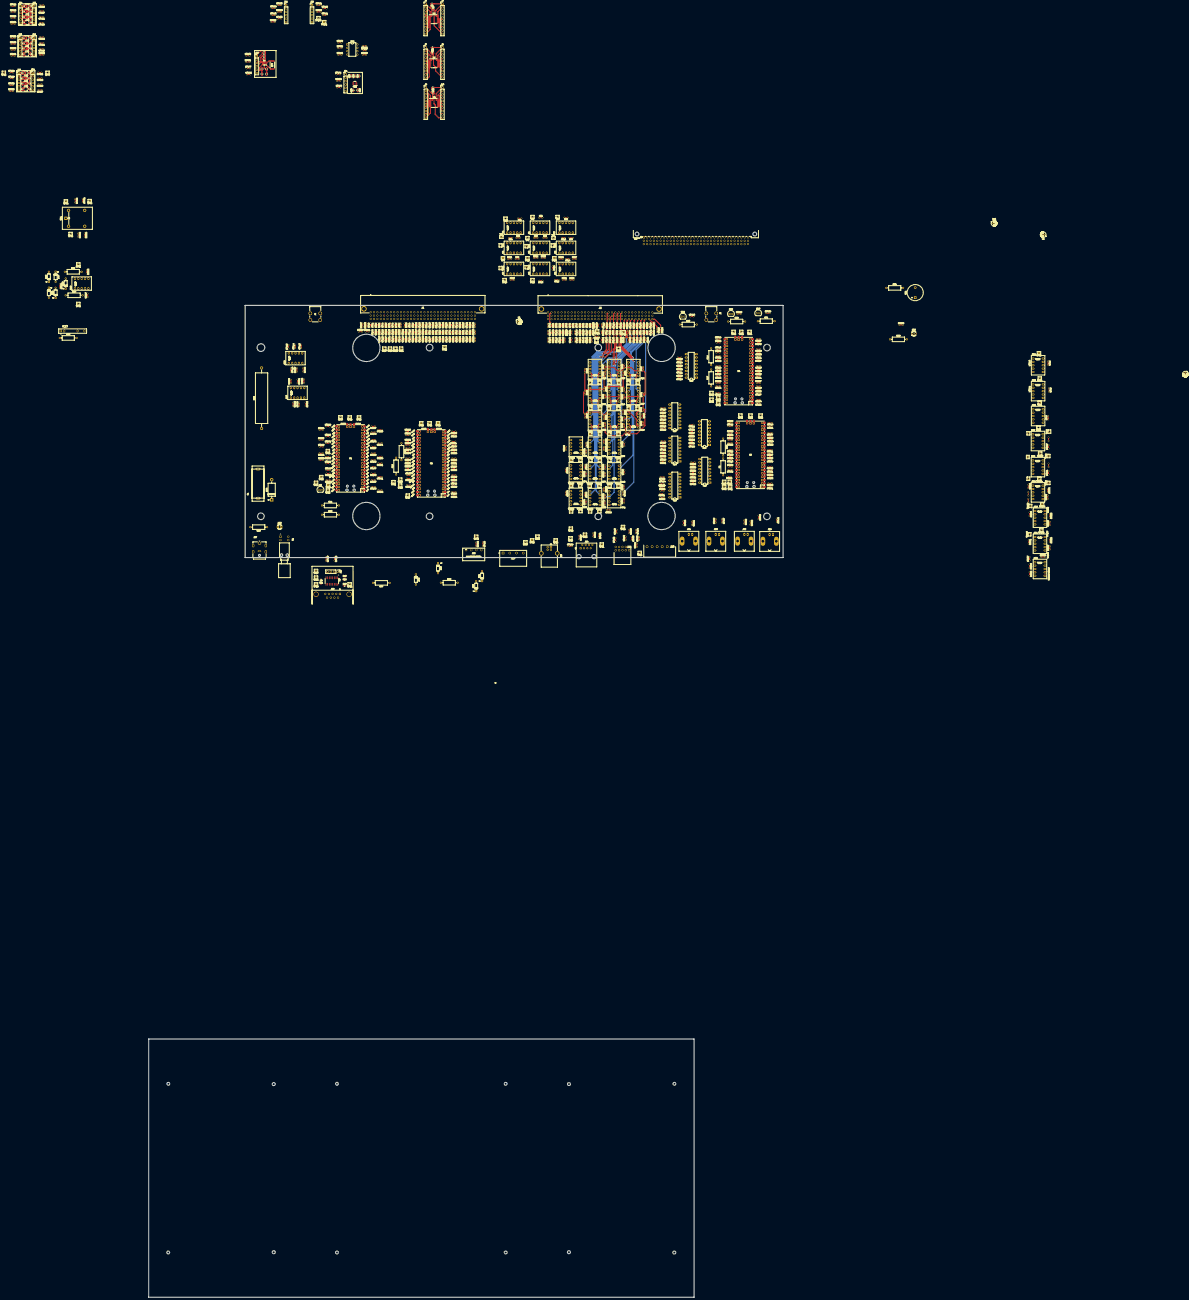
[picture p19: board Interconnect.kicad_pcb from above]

Board: 4 copper layers, 845 parts (0 on the bottom side), 979 nets.

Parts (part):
BZ1: Buzzer; Buzzer_12x9.5RM7.6
C1, C2, C16, C17: 10uF; CP_Radial_D4.0mm_P1.50mm
C3, C4, C5, C6, C7, C8, C13, C14: 0.1uF; C_0603_1608Metric_Pad1.08x0.95mm_HandSolder
C9, C10, C11, C12: 100n; C_0201_0603Metric_Pad0.64x0.40mm_HandSolder
C15: 0.1uF; C_0805_2012Metric_Pad1.18x1.45mm_HandSolder
D19, D20, D21, D22, D23, D30, D31, D32, D33: 1N4148; D_DO-35_SOD27_P7.62mm_Horizontal
D34: 1N5339B; D_DO-201_P15.24mm_Horizontal
D35: LED; LED_D3.0mm
D36: LED; LED_D3.0mm_Clear
F1: MC000827
J1, J2: 9001-11961C00A; 900111961C00A
J3, J4: 7760
J5, J6, J7, J8, J9, J10: 10x2.54mm; PinHeader_1x10_P2.54mm_Vertical
J11, J12, J13, J14, J15, J16, J30, J31, J32, J33: 6x2.54mm; PinHeader_1x06_P2.54mm_Vertical
J17: 4 Pins 5.08mm; 1146770000
J18, J19: OSCILLOSCOPE; BNC_Amphenol_B6252HB-NPP3G-50_Horizontal
J20: 6 pins 3.81mm; SHDRRA6W80P0X381_1X6_2405X920X700P
J21: AWG; BNC_Amphenol_B6252HB-NPP3G-50_Horizontal
J22: SPARE; BNC_Amphenol_B6252HB-NPP3G-50_Horizontal
J23: 691322310004
J24: RJ45; RJ45_Amphenol_54602-x08_Horizontal
J25: USB-B1HSB6; USB_B_OST_USB-B1HSxx_Horizontal
J26: 2x5 2.56mm RA; SHDRRA10W64P254_2X5_1270X910X880P
J27: PJ-082BH; CUI_PJ-082BH
J28: DB9_Female_RA; DSUB-9_Female_Horizontal_P2.77x2.84mm_EdgePinOffset4.94mm_H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
J29: Conn_01x04_Female; PinHeader_1x04_P2.54mm_Vertical
K1, K2, K3, K4, K5, K6, K7, K8, K9, K10, K11, K12, K13, K14, K15, K16, K17, K18, K19, K20, K22, K24, K25, K26, K27, K28, K29, K30, K31, K32, K33, K34, K35, K36, K37, K38, K39, K40, K41: TQ2-5; Relay_DPDT_FRT5
K21: G5LE-1; Relay_SPDT_Omron-G5LE-1
K23: CPC1706Y; RELAY_CPC1706Y
NT1: NT10_CH; NetTie-2_Front1.0mm
NT2: NT11_CH; NetTie-2_Front1.0mm
NT3: NT12_CH; NetTie-2_Front1.0mm
NT4: NT13_CH; NetTie-2_Front1.0mm
NT5: NT10_CL; NetTie-2_Front1.0mm
NT6: NT11_CL; NetTie-2_Front1.0mm
NT7: NT12_CL; NetTie-2_Front1.0mm
NT8: NT13_CL; NetTie-2_Front1.0mm
NT9: NT14_CH; NetTie-2_Front1.0mm
NT10: NT15_CH; NetTie-2_Front1.0mm
NT11: NT16_CH; NetTie-2_Front1.0mm
NT12: NT17_CH; NetTie-2_Front1.0mm
NT13: NT14_CL; NetTie-2_Front1.0mm
NT14: NT15_CL; NetTie-2_Front1.0mm
NT15: NT16_CL; NetTie-2_Front1.0mm
NT16: NT17_CL; NetTie-2_Front1.0mm
NT17, NT20: NT1S_RL; NetTie-2_Front1.0mm
NT18: NT1S_CH; NetTie-2_Front1.0mm
NT19: NT1S_NH; NetTie-2_Front1.0mm
NT21: NT1S_CL; NetTie-2_Front1.0mm
NT22: NT1S_L1; NetTie-2_Front1.0mm
NT23: NT40_CH; NetTie-2_Front1.0mm
NT24: NT41_CH; NetTie-2_Front1.0mm
NT25: NT42_CH; NetTie-2_Front1.0mm
NT26: NT43_CH; NetTie-2_Front1.0mm
NT27: NT40_CL; NetTie-2_Front1.0mm
NT28: NT41_CL; NetTie-2_Front1.0mm
NT29: NT42_CL; NetTie-2_Front1.0mm
NT30: NT43_CL; NetTie-2_Front1.0mm
NT31: NT44_CH; NetTie-2_Front1.0mm
NT32: NT45_CH; NetTie-2_Front1.0mm
NT33: NT46_CH; NetTie-2_Front1.0mm
NT34: NT47_CH; NetTie-2_Front1.0mm
NT35: NT44_CL; NetTie-2_Front1.0mm
NT36: NT45_CL; NetTie-2_Front1.0mm
NT37: NT46_CL; NetTie-2_Front1.0mm
NT38: NT47_CL; NetTie-2_Front1.0mm
NT39, NT42: NT4S_RL; NetTie-2_Front1.0mm
NT40: NT4S_CH; NetTie-2_Front1.0mm
NT41: NT4S_NH; NetTie-2_Front1.0mm
NT43: NT4S_CL; NetTie-2_Front1.0mm
NT44: NT4S_L1; NetTie-2_Front1.0mm
NT45: NT20_CH; NetTie-2_Front1.0mm
NT46: NT21_CH; NetTie-2_Front1.0mm
NT47: NT22_CH; NetTie-2_Front1.0mm
NT48: JA1; NetTie-2_Front1.0mm
NT49: JB18; NetTie-2_Front1.0mm
NT50: K10_H; NetTie-2_Front1.0mm
NT51: K31_L; NetTie-2_Front1.0mm
NT52: JA2; NetTie-2_Front1.0mm
NT53: JB19; NetTie-2_Front1.0mm
NT54: K10_L; NetTie-2_Front1.0mm
NT55: K34_H; NetTie-2_Front1.0mm
NT56: JA3; NetTie-2_Front1.0mm
NT57: JB20; NetTie-2_Front1.0mm
NT58: K13_H; NetTie-2_Front1.0mm
NT59: K34_L; NetTie-2_Front1.0mm
NT60: JA4; NetTie-2_Front1.0mm
NT61: JB21; NetTie-2_Front1.0mm
NT62: K13_L; NetTie-2_Front1.0mm
NT63: K37_H; NetTie-2_Front1.0mm
NT64: JA5; NetTie-2_Front1.0mm
NT65: JB22; NetTie-2_Front1.0mm
NT66: K16_H; NetTie-2_Front1.0mm
NT67: K37_L; NetTie-2_Front1.0mm
NT68: JA6; NetTie-2_Front1.0mm
NT69: JB23; NetTie-2_Front1.0mm
NT70: K16_L; NetTie-2_Front1.0mm
NT71: JA7; NetTie-2_Front1.0mm
NT72: JB24; NetTie-2_Front1.0mm
NT73: OCH1_H; NetTie-2_Front1.0mm
NT74: JA8; NetTie-2_Front1.0mm
NT75: JB25; NetTie-2_Front1.0mm
NT76: OCH1_L; NetTie-2_Front1.0mm
NT77: K41_H; NetTie-2_Front1.0mm
NT78: JA9; NetTie-2_Front1.0mm
NT79: JB26; NetTie-2_Front1.0mm
NT80: K20_H; NetTie-2_Front1.0mm
NT81: K41_L; NetTie-2_Front1.0mm
NT82: JA10; NetTie-2_Front1.0mm
NT83: JB27; NetTie-2_Front1.0mm
NT84: K20_L; NetTie-2_Front1.0mm
NT85: K44_H; NetTie-2_Front1.0mm
NT86: JA11; NetTie-2_Front1.0mm
NT87: JB28; NetTie-2_Front1.0mm
NT88: K23_H; NetTie-2_Front1.0mm
NT89: K44_L; NetTie-2_Front1.0mm
NT90: JA12; NetTie-2_Front1.0mm
NT91: JB29; NetTie-2_Front1.0mm
NT92: K23_L; NetTie-2_Front1.0mm
NT93: K47_H; NetTie-2_Front1.0mm
NT94: JA13; NetTie-2_Front1.0mm
NT95: JB30; NetTie-2_Front1.0mm
NT96: K26_H; NetTie-2_Front1.0mm
NT97: K47_L; NetTie-2_Front1.0mm
NT98: JA14; NetTie-2_Front1.0mm
NT99: JB31; NetTie-2_Front1.0mm
NT100: K26_L; NetTie-2_Front1.0mm
NT101: VM_I; NetTie-2_Front1.0mm
NT102: JA15; NetTie-2_Front1.0mm
NT103: JB32; NetTie-2_Front1.0mm
NT104: OCH2_H; NetTie-2_Front1.0mm
NT105: VM_T; NetTie-2_Front1.0mm
NT106: JA16; NetTie-2_Front1.0mm
NT107: JC1; NetTie-2_Front1.0mm
NT108: OCH2_L; NetTie-2_Front1.0mm
NT109: K12_H; NetTie-2_Front1.0mm
NT110: JA17; NetTie-2_Front1.0mm
NT111: JC2; NetTie-2_Front1.0mm
NT112: K30_H; NetTie-2_Front1.0mm
NT113: K12_L; NetTie-2_Front1.0mm
NT114: JA18; NetTie-2_Front1.0mm
NT115: JC3; NetTie-2_Front1.0mm
NT116: K30_L; NetTie-2_Front1.0mm
NT117: K15_H; NetTie-2_Front1.0mm
NT118: JA19; NetTie-2_Front1.0mm
NT119: JC4; NetTie-2_Front1.0mm
NT120: K33_H; NetTie-2_Front1.0mm
NT121: K15_L; NetTie-2_Front1.0mm
NT122: JA20; NetTie-2_Front1.0mm
NT123: JC5; NetTie-2_Front1.0mm
NT124: K33_L; NetTie-2_Front1.0mm
NT125: K1_CH; NetTie-2_Front1.0mm
NT126: JA21; NetTie-2_Front1.0mm
NT127: JC6; NetTie-2_Front1.0mm
NT128: K36_H; NetTie-2_Front1.0mm
NT129: K1_CL; NetTie-2_Front1.0mm
NT130: JA22; NetTie-2_Front1.0mm
NT131: JC7; NetTie-2_Front1.0mm
NT132: K36_L; NetTie-2_Front1.0mm
NT133: JA23; NetTie-2_Front1.0mm
NT134: JC8; NetTie-2_Front1.0mm
NT135: SG1_H; NetTie-2_Front1.0mm
NT136: K_OC1; NetTie-2_Front1.0mm
NT137: JA24; NetTie-2_Front1.0mm
NT138: JC9; NetTie-2_Front1.0mm
NT139: SG1_L; NetTie-2_Front1.0mm
NT140: K22_H; NetTie-2_Front1.0mm
NT141: JA25; NetTie-2_Front1.0mm
NT142: JC10; NetTie-2_Front1.0mm
NT143: K40_H; NetTie-2_Front1.0mm
NT144: K22_L; NetTie-2_Front1.0mm
NT145: JA26; NetTie-2_Front1.0mm
NT146: JC11; NetTie-2_Front1.0mm
NT147: K40_L; NetTie-2_Front1.0mm
NT148: K25_H; NetTie-2_Front1.0mm
NT149: JA27; NetTie-2_Front1.0mm
NT150: JC12; NetTie-2_Front1.0mm
NT151: K43_H; NetTie-2_Front1.0mm
NT152: K25_L; NetTie-2_Front1.0mm
NT153: RXH; NetTie-2_Front1.0mm
NT154: JC13; NetTie-2_Front1.0mm
NT155: K43_L; NetTie-2_Front1.0mm
NT156: K2_CH; NetTie-2_Front1.0mm
NT157: RXL; NetTie-2_Front1.0mm
NT158: JC14; NetTie-2_Front1.0mm
NT159: K46_H; NetTie-2_Front1.0mm
NT160: K2_CL; NetTie-2_Front1.0mm
NT161: JA30; NetTie-2_Front1.0mm
NT162: JC15; NetTie-2_Front1.0mm
NT163: K46_L; NetTie-2_Front1.0mm
NT164: TXH; NetTie-2_Front1.0mm
NT165: JC16; NetTie-2_Front1.0mm
NT166: VM_H; NetTie-2_Front1.0mm
NT167: K_OC2; NetTie-2_Front1.0mm
NT168: TXL; NetTie-2_Front1.0mm
NT169: JC17; NetTie-2_Front1.0mm
NT170: VM_L; NetTie-2_Front1.0mm
NT171: K32_H; NetTie-2_Front1.0mm
NT172: JB1; NetTie-2_Front1.0mm
NT173: JC18; NetTie-2_Front1.0mm
NT174: K11_H; NetTie-2_Front1.0mm
NT175: K32_L; NetTie-2_Front1.0mm
NT176: JB2; NetTie-2_Front1.0mm
NT177: JC19; NetTie-2_Front1.0mm
NT178: K11_L; NetTie-2_Front1.0mm
NT179: K35_H; NetTie-2_Front1.0mm
NT180: JB3; NetTie-2_Front1.0mm
NT181: JC20; NetTie-2_Front1.0mm
NT182: K14_H; NetTie-2_Front1.0mm
NT183: K35_L; NetTie-2_Front1.0mm
NT184: JB4; NetTie-2_Front1.0mm
NT185: JC21; NetTie-2_Front1.0mm
NT186: K14_L; NetTie-2_Front1.0mm
NT187: K3_CH; NetTie-2_Front1.0mm
NT188: JB5; NetTie-2_Front1.0mm
NT189: JC22; NetTie-2_Front1.0mm
NT190: K17_H; NetTie-2_Front1.0mm
NT191: K3_CL; NetTie-2_Front1.0mm
NT192: JB6; NetTie-2_Front1.0mm
NT193: JC23; NetTie-2_Front1.0mm
NT194: K17_L; NetTie-2_Front1.0mm
NT195: JB7; NetTie-2_Front1.0mm
NT196: JC24; NetTie-2_Front1.0mm
NT197: KI1_H; NetTie-2_Front1.0mm
NT198: K_OC3; NetTie-2_Front1.0mm
NT199: JB8; NetTie-2_Front1.0mm
NT200: JC25; NetTie-2_Front1.0mm
NT201: KI1_L; NetTie-2_Front1.0mm
NT202: K42_H; NetTie-2_Front1.0mm
NT203: JB9; NetTie-2_Front1.0mm
NT204: JC26; NetTie-2_Front1.0mm
NT205: K21_H; NetTie-2_Front1.0mm
NT206: K42_L; NetTie-2_Front1.0mm
NT207: JB10; NetTie-2_Front1.0mm
NT208: JC27; NetTie-2_Front1.0mm
NT209: K21_L; NetTie-2_Front1.0mm
NT210: K45_H; NetTie-2_Front1.0mm
NT211: JB11; NetTie-2_Front1.0mm
NT212: JC28; NetTie-2_Front1.0mm
NT213: K24_H; NetTie-2_Front1.0mm
NT214: K45_L; NetTie-2_Front1.0mm
NT215: JB12; NetTie-2_Front1.0mm
NT216: JC29; NetTie-2_Front1.0mm
NT217: K24_L; NetTie-2_Front1.0mm
NT218: K4_CH; NetTie-2_Front1.0mm
NT219: JB13; NetTie-2_Front1.0mm
NT220: JC30; NetTie-2_Front1.0mm
NT221: K27_H; NetTie-2_Front1.0mm
NT222: K4_CL; NetTie-2_Front1.0mm
NT223: JB14; NetTie-2_Front1.0mm
NT224: JC31; NetTie-2_Front1.0mm
NT225: K27_L; NetTie-2_Front1.0mm
NT226: VMS_H; NetTie-2_Front1.0mm
NT227: JB15; NetTie-2_Front1.0mm
NT228: JC32; NetTie-2_Front1.0mm
NT229: VMS_L; NetTie-2_Front1.0mm
NT230: JB16; NetTie-2_Front1.0mm
NT231: JB17; NetTie-2_Front1.0mm
NT232: K31_H; NetTie-2_Front1.0mm
NT233: M2_00; NetTie-2_Front1.0mm
NT234: S1_00; NetTie-2_Front1.0mm
NT235: M2_01; NetTie-2_Front1.0mm
NT236: S1_01; NetTie-2_Front1.0mm
NT237: M2_02; NetTie-2_Front1.0mm
NT238: M2_EN; NetTie-2_Front1.0mm
NT239: S1_02; NetTie-2_Front1.0mm
NT240: S1_EN; NetTie-2_Front1.0mm
NT241: M2_03; NetTie-2_Front1.0mm
NT242: S1_03; NetTie-2_Front1.0mm
NT243: M2_04; NetTie-2_Front1.0mm
NT244: M2_ADCR; NetTie-2_Front1.0mm
NT245: S1_04; NetTie-2_Front1.0mm
NT246: S1_ADC; NetTie-2_Front1.0mm
NT247: M2_05; NetTie-2_Front1.0mm
NT248: M2_ADC2; NetTie-2_Front1.0mm
NT249: S1_05; NetTie-2_Front1.0mm
NT250: S1_28; NetTie-2_Front1.0mm
NT251: M2_06; NetTie-2_Front1.0mm
NT252: M2_ADC1; NetTie-2_Front1.0mm
NT253: S1_06; NetTie-2_Front1.0mm
NT254: S1_27; NetTie-2_Front1.0mm
NT255: M2_07; NetTie-2_Front1.0mm
NT256: M2_ADC0; NetTie-2_Front1.0mm
NT257: S1_07; NetTie-2_Front1.0mm
NT258: S1_26; NetTie-2_Front1.0mm
NT259: M2_08; NetTie-2_Front1.0mm
NT260, NT264: M2_22; NetTie-2_Front1.0mm
NT261: S1_08; NetTie-2_Front1.0mm
NT262: S1_RUN; NetTie-2_Front1.0mm
NT263: M2_09; NetTie-2_Front1.0mm
NT265: S1_09; NetTie-2_Front1.0mm
NT266: S1_22; NetTie-2_Front1.0mm
NT267: M2_10; NetTie-2_Front1.0mm
NT268: M2_21; NetTie-2_Front1.0mm
NT269: S1_10; NetTie-2_Front1.0mm
NT270: S1_21; NetTie-2_Front1.0mm
NT271: M2_11; NetTie-2_Front1.0mm
NT272: M2_20; NetTie-2_Front1.0mm
NT273: S1_11; NetTie-2_Front1.0mm
NT274: S1_20; NetTie-2_Front1.0mm
NT275: M2_12; NetTie-2_Front1.0mm
NT276: M2_19; NetTie-2_Front1.0mm
NT277: S1_12; NetTie-2_Front1.0mm
NT278: S1_19; NetTie-2_Front1.0mm
NT279: M2_13; NetTie-2_Front1.0mm
NT280: M2_18; NetTie-2_Front1.0mm
NT281: S1_13; NetTie-2_Front1.0mm
NT282: S1_18; NetTie-2_Front1.0mm
NT283: M2_14; NetTie-2_Front1.0mm
NT284: M2_17; NetTie-2_Front1.0mm
NT285: S1_14; NetTie-2_Front1.0mm
NT286: S1_17; NetTie-2_Front1.0mm
NT287: M2_15; NetTie-2_Front1.0mm
NT288: M2_16; NetTie-2_Front1.0mm
NT289: S1_15; NetTie-2_Front1.0mm
NT290: S1_16; NetTie-2_Front1.0mm
NT291: S2_00; NetTie-2_Front1.0mm
NT292: S3_00; NetTie-2_Front1.0mm
NT293: S2_01; NetTie-2_Front1.0mm
NT294: S3_01; NetTie-2_Front1.0mm
NT295: S2_02; NetTie-2_Front1.0mm
NT296: S2_EN; NetTie-2_Front1.0mm
NT297: S3_02; NetTie-2_Front1.0mm
NT298: S3_EN; NetTie-2_Front1.0mm
NT299: S2_03; NetTie-2_Front1.0mm
NT300: S3_03; NetTie-2_Front1.0mm
NT301: S2_04; NetTie-2_Front1.0mm
NT302: S2_ADC; NetTie-2_Front1.0mm
NT303: S3_04; NetTie-2_Front1.0mm
NT304: S3_ADC; NetTie-2_Front1.0mm
NT305: S2_05; NetTie-2_Front1.0mm
NT306: S2_28; NetTie-2_Front1.0mm
NT307: S3_05; NetTie-2_Front1.0mm
NT308: S3_28; NetTie-2_Front1.0mm
NT309: S2_06; NetTie-2_Front1.0mm
NT310: S2_27; NetTie-2_Front1.0mm
NT311: S3_06; NetTie-2_Front1.0mm
NT312: S3_27; NetTie-2_Front1.0mm
NT313: S2_07; NetTie-2_Front1.0mm
NT314: S2_26; NetTie-2_Front1.0mm
NT315: S3_07; NetTie-2_Front1.0mm
NT316: S3_26; NetTie-2_Front1.0mm
NT317: S2_08; NetTie-2_Front1.0mm
NT318: S2_RUN; NetTie-2_Front1.0mm
NT319: S3_08; NetTie-2_Front1.0mm
NT320: S3_RUN; NetTie-2_Front1.0mm
NT321: S2_09; NetTie-2_Front1.0mm
NT322: S2_22; NetTie-2_Front1.0mm
NT323: S3_09; NetTie-2_Front1.0mm
NT324: S3_22; NetTie-2_Front1.0mm
NT325: S2_10; NetTie-2_Front1.0mm
NT326: S2_21; NetTie-2_Front1.0mm
NT327: S3_10; NetTie-2_Front1.0mm
NT328: S3_21; NetTie-2_Front1.0mm
NT329: S2_11; NetTie-2_Front1.0mm
NT330: S2_20; NetTie-2_Front1.0mm
NT331: S3_11; NetTie-2_Front1.0mm
NT332: S3_20; NetTie-2_Front1.0mm
NT333: S2_12; NetTie-2_Front1.0mm
NT334: S2_19; NetTie-2_Front1.0mm
NT335: S3_12; NetTie-2_Front1.0mm
NT336: S3_19; NetTie-2_Front1.0mm
NT337: S2_13; NetTie-2_Front1.0mm
NT338: S2_18; NetTie-2_Front1.0mm
NT339: S3_13; NetTie-2_Front1.0mm
NT340: S3_18; NetTie-2_Front1.0mm
NT341: S2_14; NetTie-2_Front1.0mm
NT342: S2_17; NetTie-2_Front1.0mm
NT343: S3_14; NetTie-2_Front1.0mm
NT344: S3_17; NetTie-2_Front1.0mm
NT345: S2_15; NetTie-2_Front1.0mm
NT346: S2_16; NetTie-2_Front1.0mm
NT347: S3_15; NetTie-2_Front1.0mm
NT348: S3_16; NetTie-2_Front1.0mm
NT349: NT23_CH; NetTie-2_Front1.0mm
NT350: NT20_CL; NetTie-2_Front1.0mm
NT351: NT21_CL; NetTie-2_Front1.0mm
NT352: NT22_CL; NetTie-2_Front1.0mm
NT353: NT23_CL; NetTie-2_Front1.0mm
NT354: NT24_CH; NetTie-2_Front1.0mm
NT355: NT25_CH; NetTie-2_Front1.0mm
NT356: NT26_CH; NetTie-2_Front1.0mm
NT357: NT27_CH; NetTie-2_Front1.0mm
NT358: NT24_CL; NetTie-2_Front1.0mm
NT359: NT25_CL; NetTie-2_Front1.0mm
NT360: NT26_CL; NetTie-2_Front1.0mm
NT361: NT27_CL; NetTie-2_Front1.0mm
NT362, NT365: NT2S_RL; NetTie-2_Front1.0mm
NT363: NT2S_CH; NetTie-2_Front1.0mm
NT364: NT2S_NH; NetTie-2_Front1.0mm
NT366: NT2S_CL; NetTie-2_Front1.0mm
NT367: NT2S_L1; NetTie-2_Front1.0mm
NT368: NT30_CH; NetTie-2_Front1.0mm
NT369: NT31_CH; NetTie-2_Front1.0mm
NT370: NT32_CH; NetTie-2_Front1.0mm
NT371: NT33_CH; NetTie-2_Front1.0mm
NT372: NT30_CL; NetTie-2_Front1.0mm
NT373: NT31_CL; NetTie-2_Front1.0mm
NT374: NT32_CL; NetTie-2_Front1.0mm
NT375: NT33_CL; NetTie-2_Front1.0mm
NT376: NT34_CH; NetTie-2_Front1.0mm
NT377: NT35_CH; NetTie-2_Front1.0mm
NT378: NT36_CH; NetTie-2_Front1.0mm
NT379: NT37_CH; NetTie-2_Front1.0mm
NT380: NT34_CL; NetTie-2_Front1.0mm
NT381: NT35_CL; NetTie-2_Front1.0mm
NT382: NT36_CL; NetTie-2_Front1.0mm
NT383: NT37_CL; NetTie-2_Front1.0mm
NT384, NT387: NT3S_RL; NetTie-2_Front1.0mm
NT385: NT3S_CH; NetTie-2_Front1.0mm
NT386: NT3S_NH; NetTie-2_Front1.0mm
NT388: NT3S_CL; NetTie-2_Front1.0mm
NT389: NT3S_L1; NetTie-2_Front1.0mm
NT390: NT10_R; NetTie-2_Front1.0mm
NT391: NT37_R; NetTie-2_Front1.0mm
NT392: NT11_R; NetTie-2_Front1.0mm
NT393: NT3S_R; NetTie-2_Front1.0mm
NT394: NT12_R; NetTie-2_Front1.0mm
NT395: NT47_R; NetTie-2_Front1.0mm
NT396: R_ADC0; NetTie-2_Front1.0mm
NT397: R_ADC1; NetTie-2_Front1.0mm
NT398: R_ADC; NetTie-2_Front1.0mm
NT399: HRL_NO1; NetTie-2_Front1.0mm
NT400: LP1_NO1; NetTie-2_Front1.0mm
NT401: HRL_C1; NetTie-2_Front1.0mm
NT402: LP1_C1; NetTie-2_Front1.0mm
NT403: HRL_NO2; NetTie-2_Front1.0mm
NT404: LP1_NC1; NetTie-2_Front1.0mm
NT405: HRL_C2; NetTie-2_Front1.0mm
NT406: LP1_NO2; NetTie-2_Front1.0mm
NT407: LP1_C2; NetTie-2_Front1.0mm
NT408: LP1_NC2; NetTie-2_Front1.0mm
NT409, NT420: SOC1; NetTie-2_Front1.0mm
NT410: NT13_R; NetTie-2_Front1.0mm
NT411: NT4S_R; NetTie-2_Front1.0mm
NT412: SOC2; NetTie-2_Front1.0mm
NT413: LP2_NO1; NetTie-2_Front1.0mm
NT414: LP2_C1; NetTie-2_Front1.0mm
NT415: LP2_NC1; NetTie-2_Front1.0mm
NT416: LP2_NO2; NetTie-2_Front1.0mm
NT417: LP2_C2; NetTie-2_Front1.0mm
NT418: LP2_NC2; NetTie-2_Front1.0mm
NT419: NT14_R; NetTie-2_Front1.0mm
NT421: NTRL1_R; NetTie-2_Front1.0mm
NT422: M1_1; NetTie-2_Front1.0mm
NT423: M1_H1; NetTie-2_Front1.0mm
NT424: M3_1; NetTie-2_Front1.0mm
NT425: M3_H1; NetTie-2_Front1.0mm
NT426: M1_2; NetTie-2_Front1.0mm
NT427: M1_H2; NetTie-2_Front1.0mm
NT428: M3_2; NetTie-2_Front1.0mm
NT429: M3_H2; NetTie-2_Front1.0mm
NT430: M1_3; NetTie-2_Front1.0mm
NT431: M1_H3; NetTie-2_Front1.0mm
NT432: M3_3; NetTie-2_Front1.0mm
NT433: M3_H3; NetTie-2_Front1.0mm
NT434: M1_4; NetTie-2_Front1.0mm
NT435: M1_H4; NetTie-2_Front1.0mm
NT436: M3_4; NetTie-2_Front1.0mm
NT437: M3_H4; NetTie-2_Front1.0mm
NT438: M2_1; NetTie-2_Front1.0mm
NT439: M2_H1; NetTie-2_Front1.0mm
NT440: M2_2; NetTie-2_Front1.0mm
NT441: M2_H2; NetTie-2_Front1.0mm
NT442: M2_3; NetTie-2_Front1.0mm
NT443: M2_H3; NetTie-2_Front1.0mm
NT444: M2_4; NetTie-2_Front1.0mm
NT445: M2_H4; NetTie-2_Front1.0mm
NT446: SCH1_H; NetTie-2_Front1.0mm
NT447: SCH1_L; NetTie-2_Front1.0mm
NT448: SCH2_H; NetTie-2_Front1.0mm
NT449: SCH2_L; NetTie-2_Front1.0mm
NT450: AWG1_H; NetTie-2_Front1.0mm
NT451: AWG1_L; NetTie-2_Front1.0mm
NT452: I1_H; NetTie-2_Front1.0mm
NT453: I1_L; NetTie-2_Front1.0mm
NT454: CTRL_3; NetTie-2_Front1.0mm
NT455: ETH6; NetTie-2_Front1.0mm
NT456: CTRL_4; NetTie-2_Front1.0mm
NT457: ETH3; NetTie-2_Front1.0mm
NT458: ETH2; NetTie-2_Front1.0mm
NT459: ETH1; NetTie-2_Front1.0mm
NT460: JTAG1; NetTie-2_Front1.0mm
NT461: JTAG4; NetTie-2_Front1.0mm
NT462: JTAG3; NetTie-2_Front1.0mm
NT463: JTAG6; NetTie-2_Front1.0mm
NT464: JTAG5; NetTie-2_Front1.0mm
NT465: JTAG7; NetTie-2_Front1.0mm
NT466: JTAG10; NetTie-2_Front1.0mm
NT467: JTAG9; NetTie-2_Front1.0mm
NT468: SER_12; NetTie-2_Front1.0mm
NT469: SER_11; NetTie-2_Front1.0mm
NT470: ERR_L; NetTie-2_Front1.0mm
NT471: I_SDA; NetTie-2_Front1.0mm
NT472, NT476: I_INH; NetTie-2_Front1.0mm
NT473: I_SCL; NetTie-2_Front1.0mm
NT474: D_SDA; NetTie-2_Front1.0mm
NT475: D_SCL; NetTie-2_Front1.0mm
NT477: I_INL; NetTie-2_Front1.0mm
NT478: EE_A0; NetTie-2_Front1.0mm
NT479: EE_SDA; NetTie-2_Front1.0mm
NT480: C_SDA; NetTie-2_Front1.0mm
NT481: C_M1; NetTie-2_Front1.0mm
NT482: EE_A1; NetTie-2_Front1.0mm
NT483: EE_SCL; NetTie-2_Front1.0mm
NT484: C_SCL; NetTie-2_Front1.0mm
NT485: C_M2; NetTie-2_Front1.0mm
NT486, NT487: EE_A2; NetTie-2_Front1.0mm
NT488: C_3; NetTie-2_Front1.0mm
NT489: C_M3; NetTie-2_Front1.0mm
NT490: C_4; NetTie-2_Front1.0mm
NT491: C_M4; NetTie-2_Front1.0mm
NT492: C_VCC; NetTie-2_Front1.0mm
NT493: C_GND; NetTie-2_Front1.0mm
NT494: NT15_R; NetTie-2_Front1.0mm
NT495: NTRL2_R; NetTie-2_Front1.0mm
NT496: NT16_R; NetTie-2_Front1.0mm
NT497: NTLED_R; NetTie-2_Front1.0mm
NT498: NT17_R; NetTie-2_Front1.0mm
NT499: NT20_R; NetTie-2_Front1.0mm
NT500: NT1S_R; NetTie-2_Front1.0mm
NT501: NT21_R; NetTie-2_Front1.0mm
NT502: NT27_R; NetTie-2_Front1.0mm
NT503: NT22_R; NetTie-2_Front1.0mm
NT504: NT2S_R; NetTie-2_Front1.0mm
NT505: NT23_R; NetTie-2_Front1.0mm
NT506: NTRH1_R; NetTie-2_Front1.0mm
NT507: NT24_R; NetTie-2_Front1.0mm
NT508: NTRS1_R; NetTie-2_Front1.0mm
NT509: NT25_R; NetTie-2_Front1.0mm
NT510: NTBP_R; NetTie-2_Front1.0mm
NT511: NT26_R; NetTie-2_Front1.0mm
NT512: NT30_R; NetTie-2_Front1.0mm
NT513: NT31_R; NetTie-2_Front1.0mm
NT514: NT32_R; NetTie-2_Front1.0mm
NT515: NT33_R; NetTie-2_Front1.0mm
NT516: NT34_R; NetTie-2_Front1.0mm
NT517: NT35_R; NetTie-2_Front1.0mm
NT518: NT36_R; NetTie-2_Front1.0mm
NT519: NT40_R; NetTie-2_Front1.0mm
NT520: NT41_R; NetTie-2_Front1.0mm
NT521: NT42_R; NetTie-2_Front1.0mm
NT522: NT43_R; NetTie-2_Front1.0mm
NT523: NT44_R; NetTie-2_Front1.0mm
NT524: NT45_R; NetTie-2_Front1.0mm
NT525: NT46_R; NetTie-2_Front1.0mm
Q19, Q22, Q24: 2N2222; TO-92_Inline
Q26, Q27, Q28, Q29, Q30, Q31, Q32, Q33, Q34, Q35, Q36, Q37: BSS138; SOT-23W
R1, R10, R11, R12, R13, R14, R16, R17: 4.7K; R_Axial_DIN0309_L9.0mm_D3.2mm_P12.70mm_Horizontal
R27, R28, R66, R67, R68, R69: 220; R_Axial_DIN0309_L9.0mm_D3.2mm_P12.70mm_Horizontal
R29: 10; R_Axial_Power_L38.0mm_W9.0mm_P45.72mm
R31, R35, R40: 10K; R_Axial_DIN0309_L9.0mm_D3.2mm_P12.70mm_Horizontal
R36: 470; R_Axial_DIN0309_L9.0mm_D3.2mm_P12.70mm_Horizontal
R42, R43, R44, R45, R46, R47, R48, R49, R50, R51, R52, R53, R54, R55, R56, R57, R58, R59, R60, R61, R62, R63, R64, R65: 10K; R_0603_1608Metric
R71: 0; R_Axial_DIN0309_L9.0mm_D3.2mm_P12.70mm_Horizontal
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

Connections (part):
1WIRE: NT267.1, NT428.1
1W_DATA: NT177.1, NT429.1
/Communication/M2_HV1: J12.1, J16.1, NT423.2, NT439.2, Q26.3 (D), Q34.3 (D), R43.1, R59.1
/Communication/M2_HV2: J12.2, J16.2, NT427.2, NT441.2, Q28.3 (D), Q35.3 (D), R47.1, R61.1
/Communication/M2_HV3: J12.5, J16.5, NT431.2, NT443.2, Q30.3 (D), Q36.3 (D), R51.1, R63.1
/Communication/M2_HV4: J12.6, J16.6, NT435.2, NT445.2, Q32.3 (D), Q37.3 (D), R55.1, R65.1
/Communication/M2_LV1: J11.1, J15.1, NT422.2, NT438.2, Q26.2 (S), Q34.2 (S), R42.1, R58.1
/Communication/M2_LV2: J11.2, J15.2, NT426.2, NT440.2, Q28.2 (S), Q35.2 (S), R46.1, R60.1
/Communication/M2_LV3: J11.5, J15.5, NT430.2, NT442.2, Q30.2 (S), Q36.2 (S), R50.1, R62.1
/Communication/M2_LV4: J11.6, J15.6, NT434.2, NT444.2, Q32.2 (S), Q37.2 (S), R54.1, R64.1
/Communication/M3_HV1: J14.1, NT425.2, Q27.3 (D), R45.1
/Communication/M3_HV2: J14.2, NT429.2, Q29.3 (D), R49.1
/Communication/M3_HV3: J14.5, NT433.2, Q31.3 (D), R53.1
/Communication/M3_HV4: J14.6, NT437.2, Q33.3 (D), R57.1
/Communication/M3_LV1: J13.1, NT424.2, Q27.2 (S), R44.1
/Communication/M3_LV2: J13.2, NT428.2, Q29.2 (S), R48.1
/Communication/M3_LV3: J13.5, NT432.2, Q31.2 (S), R52.1
/Communication/M3_LV4: J13.6, NT436.2, Q33.2 (S), R56.1
/OtherRessource/K1C1: K20.8, NT402.2
/OtherRessource/K1C2: K20.3, NT407.2
/OtherRessource/K2C1: K22.8, NT414.2
/OtherRessource/K2C2: K22.3, NT417.2
/Pico_master/S1_I2C_ID0: NT258.2, R12.2
/Pico_master/S1_I2C_ID1: NT254.2, R13.2
/Pico_master/S2_I2C_ID0: NT314.2, R14.2
/Pico_master/S2_I2C_ID1: NT310.2, R1.2
/Pico_master/S3_I2C_ID0: NT316.2, R16.2
/Pico_master/S3_I2C_ID1: NT312.2, R17.2
/Pico_master/SYNC: NT264.2, NT266.2, NT322.2, NT324.2
/Relay_Bank1/B10_CH: K1.8, NT1.2
/Relay_Bank1/B10_CL: K1.3, NT5.2
/Relay_Bank1/B11_CH: K2.8, NT2.2
/Relay_Bank1/B11_CL: K2.3, NT6.2
/Relay_Bank1/B12_CH: K3.8, NT3.2
/Relay_Bank1/B12_CL: K3.3, NT7.2
/Relay_Bank1/B13_CH: K4.8, NT4.2
/Relay_Bank1/B13_CL: K4.3, NT8.2
/Relay_Bank1/B14_CH: K5.8, NT9.2
/Relay_Bank1/B14_CL: K5.3, NT13.2
/Relay_Bank1/B15_CH: K6.8, NT10.2
/Relay_Bank1/B15_CL: K6.3, NT14.2
/Relay_Bank1/B16_CH: K7.8, NT11.2
/Relay_Bank1/B16_CL: K7.3, NT15.2
/Relay_Bank1/B17_CH: K8.8, NT12.2
/Relay_Bank1/B17_CL: K8.3, NT16.2
/Relay_Bank1/BANK1_BUS_H: NT5.1, NT6.1, NT7.1, NT8.1, NT13.1, NT14.1, NT15.1, NT16.1, NT19.2, NT20.2
/Relay_Bank1/BANK1_BUS_L: NT1.1, NT2.1, NT3.1, NT4.1, NT9.1, NT10.1, NT11.1, NT12.1, NT17.2, NT22.2
/Relay_Bank2/B20_CH: K24.8, NT45.2
/Relay_Bank2/B20_CL: K24.3, NT350.2
/Relay_Bank2/B21_CH: K25.8, NT46.2
/Relay_Bank2/B21_CL: K25.3, NT351.2
/Relay_Bank2/B22_CH: K26.8, NT47.2
/Relay_Bank2/B22_CL: K26.3, NT352.2
/Relay_Bank2/B23_CH: K27.8, NT349.2
/Relay_Bank2/B23_CL: K27.3, NT353.2
/Relay_Bank2/B24_CH: K28.8, NT354.2
/Relay_Bank2/B24_CL: K28.3, NT358.2
/Relay_Bank2/B25_CH: K29.8, NT355.2
/Relay_Bank2/B25_CL: K29.3, NT359.2
/Relay_Bank2/B26_CH: K30.8, NT356.2
/Relay_Bank2/B26_CL: K30.3, NT360.2
/Relay_Bank2/B27_CH: K31.8, NT357.2
/Relay_Bank2/B27_CL: K31.3, NT361.2
/Relay_Bank2/BANK2_BUS_H: NT350.1, NT351.1, NT352.1, NT353.1, NT358.1, NT359.1, NT360.1, NT361.1, NT364.2, NT365.2
/Relay_Bank2/BANK2_BUS_L: NT45.1, NT46.1, NT47.1, NT349.1, NT354.1, NT355.1, NT356.1, NT357.1, NT362.2, NT367.2
/Relay_Bank3/B30_CH: K33.8, NT368.2
/Relay_Bank3/B30_CL: K33.3, NT372.2
/Relay_Bank3/B31_CH: K34.8, NT369.2
/Relay_Bank3/B31_CL: K34.3, NT373.2
/Relay_Bank3/B32_CH: K35.8, NT370.2
/Relay_Bank3/B32_CL: K35.3, NT374.2
/Relay_Bank3/B33_CH: K36.8, NT371.2
/Relay_Bank3/B33_CL: K36.3, NT375.2
/Relay_Bank3/B34_CH: K37.8, NT376.2
/Relay_Bank3/B34_CL: K37.3, NT380.2
/Relay_Bank3/B35_CH: K38.8, NT377.2
/Relay_Bank3/B35_CL: K38.3, NT381.2
/Relay_Bank3/B36_CH: K39.8, NT378.2
/Relay_Bank3/B36_CL: K39.3, NT382.2
/Relay_Bank3/B37_CH: K40.8, NT379.2
/Relay_Bank3/B37_CL: K40.3, NT383.2
/Relay_Bank3/BANK3_BUS_H: NT372.1, NT373.1, NT374.1, NT375.1, NT380.1, NT381.1, NT382.1, NT383.1, NT386.2, NT387.2
/Relay_Bank3/BANK3_BUS_L: NT368.1, NT369.1, NT370.1, NT371.1, NT376.1, NT377.1, NT378.1, NT379.1, NT384.2, NT389.2
/Relay_Bank4/B40_CH: K10.8, NT23.2
/Relay_Bank4/B40_CL: K10.3, NT27.2
/Relay_Bank4/B41_CH: K11.8, NT24.2
/Relay_Bank4/B41_CL: K11.3, NT28.2
/Relay_Bank4/B42_CH: K12.8, NT25.2
/Relay_Bank4/B42_CL: K12.3, NT29.2
/Relay_Bank4/B43_CH: K13.8, NT26.2
/Relay_Bank4/B43_CL: K13.3, NT30.2
/Relay_Bank4/B44_CH: K14.8, NT31.2
/Relay_Bank4/B44_CL: K14.3, NT35.2
/Relay_Bank4/B45_CH: K15.8, NT32.2
/Relay_Bank4/B45_CL: K15.3, NT36.2
/Relay_Bank4/B46_CH: K16.8, NT33.2
/Relay_Bank4/B46_CL: K16.3, NT37.2
/Relay_Bank4/B47_CH: K17.8, NT34.2
/Relay_Bank4/B47_CL: K17.3, NT38.2
/Relay_Bank4/BANK4_BUS_H: NT27.1, NT28.1, NT29.1, NT30.1, NT35.1, NT36.1, NT37.1, NT38.1, NT41.2, NT42.2
/Relay_Bank4/BANK4_BUS_L: NT23.1, NT24.1, NT25.1, NT26.1, NT31.1, NT32.1, NT33.1, NT34.1, NT39.2, NT44.2
/i2c_device/DAC_SCL: J31.3, NT474.2, R76.1, U11.5 (SCL)
/i2c_device/DAC_SDA: J31.4, NT475.2, R75.1, U11.4 (SDA)
/i2c_device/I_SCL: J30.3, NT473.2, R73.1, U10.5 (SCL)
/i2c_device/I_SDA: J30.4, NT471.2, R74.1, U10.6 (SDA)
/i2c_device/VIN+: J30.6, NT472.2, R77.2, U10.1 (IN+)
/i2c_device/VIN-: J30.5, NT477.2, R77.1, U10.2 (IN-)
ADC0: D19.2 (A), D20.1 (K), NT256.1, R27.1
ADC1: D21.2 (A), D22.1 (K), NT252.1, R28.1
AWG_H: NT135.2, NT450.1
AWG_L: NT139.2, NT451.1
B1S_D: NT334.1, U15.2 (I2)
B1S_R: K9.10, NT500.2
B1_COM_H: NT18.1, NT125.1
B1_COM_L: NT21.1, NT129.1
B2S_D: NT338.1, U15.4 (I4)
B2S_R: K32.10, NT504.2
B2_COM_H: NT156.1, NT363.1
B2_COM_L: NT160.1, NT366.1
B3S_D: NT336.1, U14.2 (I2)
B3S_R: K41.10, NT393.2
B3_COM_H: NT187.1, NT385.1
B3_COM_L: NT191.1, NT388.1
B4S_D: NT340.1, U14.4 (I4)
B4S_R: K18.10, NT411.2
B4_COM_H: NT40.1, NT218.1
B4_COM_L: NT43.1, NT222.1
B10_D: NT291.1, U13.1 (I1)
B10_H: K1.7, NT50.2
B10_L: K1.4, NT54.2
B10_R: K1.10, NT390.2
B11_D: NT293.1, U13.2 (I2)
B11_H: K2.7, NT174.2
B11_L: K2.4, NT178.2
B12_D: NT295.1, U13.3 (I3)
B12_H: K3.7, NT109.2
B12_L: K3.4, NT113.2
B12_R: K3.10, NT394.2
B13_D: NT299.1, U13.4 (I4)
B13_H: K4.7, NT58.2
B13_L: K4.4, NT62.2
B13_R: K4.10, NT410.2
B14_D: NT301.1, U13.5 (I5)
B14_H: K5.7, NT182.2
B14_L: K5.4, NT186.2
B14_R: K5.10, NT419.2
B15_D: NT305.1, U13.6 (I6)
B15_H: K6.7, NT117.2
B15_L: K6.4, NT121.2
B15_R: K6.10, NT494.2
B16_D: NT309.1, U13.7 (I7)
B16_H: K7.7, NT66.2
B16_L: K7.4, NT70.2
B16_R: K7.10, NT496.2
B17_D: NT313.1, U15.1 (I1)
B17_H: K8.7, NT190.2
B17_L: K8.4, NT194.2
B17_R: K8.10, NT498.2
B20_D: NT325.1, U16.1 (I1)
B20_H: K24.7, NT80.2
B20_L: K24.4, NT84.2
B20_R: K24.10, NT499.2
B21_D: NT329.1, U16.2 (I2)
B21_H: K25.7, NT205.2
B21_L: K25.4, NT209.2
B21_R: K25.10, NT501.2
B22_D: NT333.1, U16.3 (I3)
B22_H: K26.7, NT140.2
B22_L: K26.4, NT144.2
B22_R: K26.10, NT503.2
B23_D: NT337.1, U16.4 (I4)
B23_H: K27.7, NT88.2
B23_L: K27.4, NT92.2
B23_R: K27.10, NT505.2
B24_D: NT341.1, U16.5 (I5)
B24_H: K28.7, NT213.2
B24_L: K28.4, NT217.2
B24_R: K28.10, NT507.2
B25_D: NT345.1, U16.6 (I6)
B25_H: K29.7, NT148.2
B25_L: K29.4, NT152.2
B25_R: K29.10, NT509.2
B26_D: NT346.1, U16.7 (I7)
B26_H: K30.7, NT96.2
B26_L: K30.4, NT100.2
B26_R: K30.10, NT511.2
B27_D: NT342.1, U15.3 (I3)
B27_H: K31.7, NT221.2
B27_L: K31.4, NT225.2
B27_R: K31.10, NT502.2
B30_D: NT292.1, U17.1 (I1)
B30_H: K33.7, NT112.2
B30_L: K33.4, NT116.2
B30_R: K33.10, NT512.2
B31_D: NT294.1, U17.2 (I2)
B31_H: K34.7, NT232.2
B31_L: K34.4, NT51.2
B32_D: NT297.1, U17.3 (I3)
B32_H: K35.7, NT171.2
B32_L: K35.4, NT175.2
B32_R: K35.10, NT514.2
B33_D: NT300.1, U17.4 (I4)
B33_H: K36.7, NT120.2
B33_L: K36.4, NT124.2
B33_R: K36.10, NT515.2
B34_D: NT303.1, U17.5 (I5)
B34_H: K37.7, NT55.2
B34_L: K37.4, NT59.2
B34_R: K37.10, NT516.2
B35_D: NT307.1, U17.6 (I6)
B35_H: K38.7, NT179.2
B35_L: K38.4, NT183.2
B35_R: K38.10, NT517.2
B36_D: NT311.1, U17.7 (I7)
B36_H: K39.7, NT128.2
B36_L: K39.4, NT132.2
B36_R: K39.10, NT518.2
B37_D: NT315.1, U14.1 (I1)
B37_H: K40.7, NT63.2
B37_L: K40.4, NT67.2
B37_R: K40.10, NT391.2
B40_D: NT327.1, U18.1 (I1)
B40_H: K10.7, NT143.2
B40_L: K10.4, NT147.2
B40_R: K10.10, NT519.2
B41_D: NT331.1, U18.2 (I2)
B41_H: K11.7, NT77.2
B41_L: K11.4, NT81.2
B41_R: K11.10, NT520.2
B42_D: NT335.1, U18.3 (I3)
B42_H: K12.7, NT202.2
B42_L: K12.4, NT206.2
B42_R: K12.10, NT521.2
B43_D: NT339.1, U18.4 (I4)
B43_H: K13.7, NT151.2
B43_L: K13.4, NT155.2
B43_R: K13.10, NT522.2
B44_D: NT343.1, U18.5 (I5)
B44_H: K14.7, NT85.2
B44_L: K14.4, NT89.2
B44_R: K14.10, NT523.2
B45_D: NT347.1, U18.6 (I6)
B45_H: K15.7, NT210.2
B45_L: K15.4, NT214.2
B45_R: K15.10, NT524.2
B46_D: NT348.1, U18.7 (I7)
B46_H: K16.7, NT159.2
B46_L: K16.4, NT163.2
B46_R: K16.10, NT525.2
B47_D: NT344.1, U14.3 (I3)
B47_H: K17.7, NT93.2
B47_L: K17.4, NT97.2
B47_R: K17.10, NT395.2
BEEPER: NT271.1, U15.7 (I7)
BEEP_D: NT510.2, R71.1
CMOD_1: NT107.1, NT481.2
CMOD_2: NT111.1, NT485.2
CMOD_3: NT115.1, NT489.2
CMOD_4: NT119.1, NT491.2
CTRL: J7.8, NT278.1, U7.8 (A7)
CUR_SENS_H: NT185.1, NT472.1
CUR_SENS_L: NT189.1, NT477.1
DAC_VOUT: J31.1, NT184.1, NT476.1, NT476.2, U11.1 (VOUT)
DIG_PWR_IN: C4.1, C6.1, C8.1, J6.1, J8.1, J10.1, J12.3, J14.3, J16.3, NT208.1, R43.2, R45.2, R47.2, R49.2, R51.2, R53.2, R55.2, R57.2, R59.2, R61.2, R63.2, R65.2, U6.19 (VCCB), U7.19 (VCCB), U8.19 (VCCB)
DVM_H: J20.1, NT166.2
DVM_I: J20.3, NT101.2
DVM_L: J20.2, NT170.2
DVM_SENSE_H: J20.4, NT226.2
DVM_SENSE_L: J20.5, NT229.2
DVM_TRIG: J20.6, NT105.2
ERROR_LED: NT276.1, U14.7 (I7)
ERR_LED: J7.5, NT470.2, U7.5 (A4)
ETH_RX+: NT153.1, NT457.1
ETH_RX-: NT157.1, NT455.1
ETH_TX+: NT164.1, NT459.1
ETH_TX-: NT168.1, NT458.1
EXT_16: NT288.1, NT490.1
EXT_17: NT284.1, NT488.1
Earth: J1.MH1, J1.MH2, J2.MH1, J2.MH2, J3.1, J3.2, J3.3, J3.4, J4.1, J4.2, J4.3, J4.4, J25.5 (Shield), J27.S1 (SHIELD), J27.S2 (SHIELD), J27.S3 (SHIELD), J27.S4 (SHIELD), J28.0 (PAD)
FLAG: J7.9, NT282.1, U7.9 (A8)
GND: C1.2, C2.2, C3.2, C4.2, C5.2, C6.2, C7.2, C8.2, C9.2, C10.2, C13.2, C14.2, C15.2, C16.2, C17.2, D20.2 (A), D22.2 (A), D23.2 (A), D31.2 (A), D33.2 (A), D34.2 (A), D35.2 (A), J2.C7, J2.C15, J2.C23, J6.10, J8.10, J10.10, J11.4, J12.4, J13.4, J14.4, J15.4, J16.4, J28.5, J29.4, J30.2, J31.2, J31.6, K19.10, NT98.1, NT161.1, NT180.1, NT181.1, NT188.1, NT456.1, NT478.1, NT482.1, NT486.1, NT487.1, NT493.1, Q19.1 (E), Q22.1 (E), Q24.1 (E), R1.1, R12.1, R13.1, R14.1, R16.1, R17.1, R81.1, R82.1, R83.1, S1.4, U1.3 (GND), U1.8 (GND), U1.13 (GND), U1.18 (GND), U1.23 (GND), U1.28 (GND), U1.33 (AGND), U1.38 (GND), U2.3 (GND), U2.8 (GND), U2.13 (GND), U2.18 (GND), U2.23 (GND), U2.28 (GND), U2.33 (AGND), U2.38 (GND)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
HPR1: NT319.1, U15.5 (I5)
HPR1_R: K21.2, NT506.2
I2C0_SCL: NT268.1, NT270.2, NT326.2, NT328.2, NT473.1, NT474.1, NT479.1, NT480.1, R10.1
I2C0_SDA: NT272.1, NT274.2, NT330.2, NT332.2, NT471.1, NT475.1, NT483.1, NT484.1, R11.1
I2C1_SCL: NT255.1, NT436.1
I2C1_SDA: NT251.1, NT432.1
I2C_SCL: NT94.1, NT437.1
I2C_SDA: NT90.1, NT433.1
INST_H: NT197.1, NT452.1
INST_L: NT201.1, NT453.1
JTAG_IGND: NT122.1, NT463.1
JTAG_OGND: NT110.1, NT461.1
JTAG_TCK: NT126.1, NT467.1
JTAG_TDI: NT118.1, NT464.1
JTAG_TDO: NT106.1, NT462.1
JTAG_TGND: NT130.1, NT466.1
JTAG_TMS: NT114.1, NT465.1
JTAG_TRST: NT102.1, NT460.1
K1_LP_C1: NT195.1, NT402.1
K1_LP_C2: NT131.1, NT407.1
K1_LP_NC1: NT203.1, NT404.2
K1_LP_NC2: NT138.1, NT408.2
K1_LP_NO1: NT199.1, NT400.2
K1_LP_NO2: NT134.1, NT406.2
K2_LP_C1: NT207.1, NT414.1
K2_LP_C2: NT142.1, NT417.1
K2_LP_NC1: NT215.1, NT415.2
K2_LP_NC2: NT150.1, NT418.2
K2_LP_NO1: NT211.1, NT413.2
K2_LP_NO2: NT146.1, NT416.2
K3_HP_C1: NT154.1, NT401.1
K3_HP_C2: NT158.1, NT405.1
K3_HP_NO1: NT162.1, NT399.2
K3_HP_NO2: NT165.1, NT403.2
LPR1: NT317.1, U14.5 (I5)
LPR1_R: K20.10, NT421.2
LPR2: NT321.1, U14.6 (I6)
LPR2_R: K22.10, NT495.2
M1_IO8: D30.2 (A), D31.1 (K), J7.2, NT259.1, R66.1, U7.1 (A1)
M1_IO9: D32.2 (A), D33.1 (K), J7.3, NT263.1, R67.1, U7.3 (A2)
M1_IO28: J7.4, NT248.1, U7.4 (A3)
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

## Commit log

2023-01-09 First commit
    Initial schematics
    [AlertDevice.kicad_sch, Interconnect.kicad_pcb, Interconnect.kicad_sch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]
2023-01-16 First try to fit electronic on PCB
    [AlertDevice.kicad_sch, Interconnect.csv, Interconnect.kicad_pcb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]
2023-01-23 backup 1 bank done
    [AlertDevice.kicad_sch, Bank1_Relay.kicad_sch, Interconnect.kicad_pcb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]
2023-02-13 Relay bank wired
    [Interconnect.kicad_pcb]
2023-02-17 half PCB completed
    FTS io controller PCB
    [AlertDevice.kicad_sch, Interconnect.kicad_sch, MainInput.kicad_sch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]
2023-02-28 PCB Completed
    PCB completed but final verification not completed
    [AlertDevice.kicad_sch, Interconnect.kicad_sch, MainInput.kicad_sch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]
2023-03-06 PCB completed
    All modification made
    [AlertDevice.kicad_sch, communication.kicad_sch, fconnect.kicad_sch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]
2023-03-06 PCB completed
    [Interconnect.kicad_sch]
2023-03-06 small update silkscreen
    [MainInput.kicad_sch]
2023-03-07 Change custom connector
    Use 8 pins to replace 6 pins
    [Interconnect-B_Cu.gbl, Interconnect-B_Mask.gbs, Interconnect-B_Paste.gbp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]
2023-05-16 update
    Correction of small error
    [AlertDevice.kicad_sch, Interconnect.kicad_sch, MainInput.kicad_sch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]
2023-08-09 V1.0 Commit
    PCB Design Completed
    [AlertDevice.kicad_sch, Bank1_Relay.kicad_sch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]
2024-11-22 Doc moved to Libreoffice
    [AlertDevice.kicad_sch, BOM_InterconnectIO_Board_600-1000.ods, Bank1_Relay.kicad_sch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]
2024-11-22 correct link on readme
    [AlertDevice.kicad_sch, Bank1_Relay.kicad_sch, Interconnect-B_Fab.dxf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]
2024-11-22 remove not necessary files
    [Bank1_Relay.kicad_sch]
2024-12-02 Change TO-92 package to 2.54mm package
    Transistor and voltage reference using TO-92 Package will have the possibility to be mounted on in-line 3 pins socket of 2.54mm.
    [AlertDevice.kicad_sch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]
2025-01-08 add documentation partnumber and add BOM Pico controller socket and header
    [BOM_InterconnectIO_Board_600-1000.ods]
2025-01-08 add partnumber to documentation
    [BOM_InterconnectIO_Board_600-1000.ods, BOM_InterconnectIO_Board_610-1000.ods]
2025-02-06 Reverse COM_H and COM_L on relay Bank
    [Interconnect-B_Courtyard.gbr, Interconnect-B_Cu.gbl, Interconnect-B_Cu.gbr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]

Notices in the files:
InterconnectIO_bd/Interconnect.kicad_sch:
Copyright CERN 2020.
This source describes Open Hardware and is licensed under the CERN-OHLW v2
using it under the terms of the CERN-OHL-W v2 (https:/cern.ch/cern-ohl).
